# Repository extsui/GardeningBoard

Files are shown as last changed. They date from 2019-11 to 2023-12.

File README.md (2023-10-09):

# GardeningBoard
## 概要
- ガーデニングボードは着脱可能基板を自由に抜き差しして自分好みの作品を生み出せるというコンセプトの作品です。
- 当初はガーデニングにちなんで庭関連の基板ばかり作っていましたが、現在はガーデニングという手法をベースにした表現に概念を拡張しています。
  - 系譜：KawaiiMakeMyBoard --> GardeningBoard --> Fountain

## 基板
| 基板名 | 形状 | 概要 | 組み上げ対象作品 |
|---|---|---|---|
| Grass | 草 | 挿入部品 | GardeningBoard 等 |
| Tree | 木 | 挿入部品 | GardeningBoard 等 |
| House | 家 | 挿入部品 | GardeningBoard 等 |
| Land | 正方形 (旧式)・上部側 | 挿入部品用穴付き・半田接合式 | KawaiiMakeMyBoard 専用 |
| Base | 正方形 (旧式)・下部側 | カードエッジコネクタ土台 | KawaiiMakeMyBoard 専用 |
| Tile | 正六角形・上部側 | 挿入部品用穴付き | GardeningBoard 等 |
| Ground | 正六角形・下部側 | STM32F303 使用、Pillar からの信号を挿入分に分配<br>STM 未実装を Base の代わりとしても使用 | GardeningBoard 専用 |
| Pillar | 正六角形・最下部側 | SeeduinoXIAO 使用、単体動作可、GardeningBoard 制御の最上位 | GardeningBoard 専用 |
| Building | 縦長長方形・挿入部品  | 7セグ6桁x6行、GardeningBoard と互換性無し | 新規 |
| Fountain | 正六角形・下部側 | XIAO-ESP32C3 使用、Building・Tile 想定 | 新規 |

※順番は開発順

## プログラム
- Firmware/Balan
  - Ground に搭載されている STM32F303 向けのプログラム
  - 上位 I2C から受け取ったデータ (点灯パターン等) を元に、下位 I2C に接続されている HT16K33 を制御する
- M5Stack/Pump
  - PC から USB シリアル経由で受信したデータを Balan に送信する M5Stack 向けのプログラム
  - Balan への送信は I2C に変換して GROVE ケーブル経由で行う
  - GardeningBoard 開発時向けに使用したもので、GardeningBoard 最終系には含まれていない
- Tools/PruningTool
  - Pump と対応する PC 側の制御ツール (C# フォームアプリ)
  - 草/木/家/土等の基本パーツ一つ一つの点灯パターン作成・検討に使用
- Seeedino/Pillar
  - Pillar 基板に搭載されている SeeeduinoXIAO 向けのプログラム
  - PC から USB シリアル経由で受信したデータを Balan に送信する (Pump と立ち位置は似ている)
  - スタンドアローン動作も想定している
  - Pillar 基板に搭載されている以下を制御する
    - タクトスイッチ (状態遷移用)
    - DFPlayerMp3 基板 (音楽再生用)
    - microSD (点灯表示シナリオ読み込み用)
    - ボリューム2個 (輝度調整・表示周期変更用)
    - I2C マスタ GROVE コネクタ (Balan への信号用)
    - 0.96 inch I2C 有機 EL グラフィックス表示器 (各種情報表示用)
- Tools/Sprinkler
  - Pillar と対応する PC 側の制御ツール (C# WPF)
  - PruningTool のように基本パーツの点灯パターン検討も出来なくはないが、<br>Sprinkler はどちらかというと点灯パターンを組み合わせた GardeningBoard 全体の表示シナリオ検討・作成に使用することを想定
  - 表示シナリオ検討は以下の手順で行う
    - GardeningBoard (Pillar) と接続する
    - リアルタイム制御用のテキストボックスにフォーカスを当てた状態にする
    - キーボードのキーそれぞれに各パーツと表示パターンが割り当ててあるので自由にキー入力する
  - 作成した表示シナリオを Pillar で再生できる形式に変換・ファイル出力できる (ハズ)
- Tools/PatternConverter
  - 基本パーツの複雑な点灯パターン検討・作成用の Python スクリプト
  - 点灯パターンは yml ファイルで定義し、以下の二つに変換する
    - C/C++ 形式 (Balan のプログラムに埋め込む用)
    - C# 形式 (Sprinkler のシナリオ検討で点灯パターンを入力補完するためのパターン enum 定義用)
- Tools/BuildingPainter
  - TODO:

※順番は開発順

## 代表的な構成
### KawaiiMakeMyBoard 
| 基板名 | 個数 |
|---|---|
| Grass  | 2 |
| Tree | 1 |
| Land | 1 |
| Base | 1 |

### GardeningBoard
| 基板名 | 個数 | 備考 |
|---|---|---|
| Grass  | 3 | 手前側に3個 |
| Tree | 3 | 奥側に3個 |
| House  | 1 | 中央に1個 |
| Tile | 7 | - |
| Ground | 7 | STM 実装は2個、残りは中継用 |
| Pillar | 1 | 中央基板のさらに下に配置 |

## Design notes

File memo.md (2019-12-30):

# リリース履歴
- Grass v1.0
    - D12のシルクが逆向きになっている。
        ネットリスト再読み込みすれば逆向きであることがわかる。
    
- Grass v2.0
    - D12のシルク不具合修正。
    - カードエッジコネクタ5Pに修正。

# Tips
- KiCADのガバーデータの名前を変更しなくても発注できることを確認。(2019/05/26)

# 不具合/改善/対策メモ
- Grassで、カードエッジコネクタ部のベタが下にちょっと喰い込んでてイマイチ。
    下層のLEDのベタのY座標と合わせた方がいいかも。(2019/06/01)
- Baseで、GROVEコネクタは上方向にスペース的に刺せない。
    L字コネクタを刺そうとすると向き的に下方向にしか刺せない。
    -->コネクタ(配線)の向きを変える必要がある。

# 作品名案
- Gardening Board (外向け)
- KawaiiMakeMYBoard (内向け)
    ※でも流す曲はYPT？
- えくすとのアトリエ
- Extronics Gerden (Ext + -tronicsの造語)
- こころの庭
- Grass Growing

# アイデア
- 木の上に星つける
- 土台は黒色が落ち着くかも？
- 土台を六角形構造にする
    - パーツの底面が枠外に飛び出るのは見栄えが悪いので
      六角形にするなら10cm*10cmの枠を越えるのは必須。
    - --> 10cm*10cmにちょうど収まる形式とする方向で確定。

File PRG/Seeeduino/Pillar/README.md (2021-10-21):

# フォルダ構成
- Sd/
  - XIAO から読み込む SD カードのルートに格納するデータ。
    ※DFPlayerMini の SD に保存する BadApple の mp3 は
      リポジトリには含めないので別途用意すること。
- Make/
  - BadApple 用データ生成スクリプトおよび生成用フォルダ。

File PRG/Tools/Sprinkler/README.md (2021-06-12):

# Sprinkler

## 実行手順
以下のフォルダ構成で Sprinkler.exe を実行してください。
```
.
├── Sprinkler.exe
└── Music/
    ├── Wizards_in_Winter.mp3
    ├── ...(曲を増やす場合)
    └── ...(同上)
```

## 設計メモ
### MIDI ライブラリ
MIDI ライブラリの選定基準は以下の通り。
- MIDI 鍵盤からキー入力とベロシティを取得できること。
- 使い勝手がシンプルであること。

上記から midi-dot-net を選択した。

補足メモは以下の通り。
- NuGet でトップに出るのは managed-midi だが複雑そうだったので却下
- midi-dot-net にサンプルがついててわかりやすかった
- だが midi-dot-net が .NETCore 未対応でプロジェクトを
  .NETFramework に戻す羽目に…

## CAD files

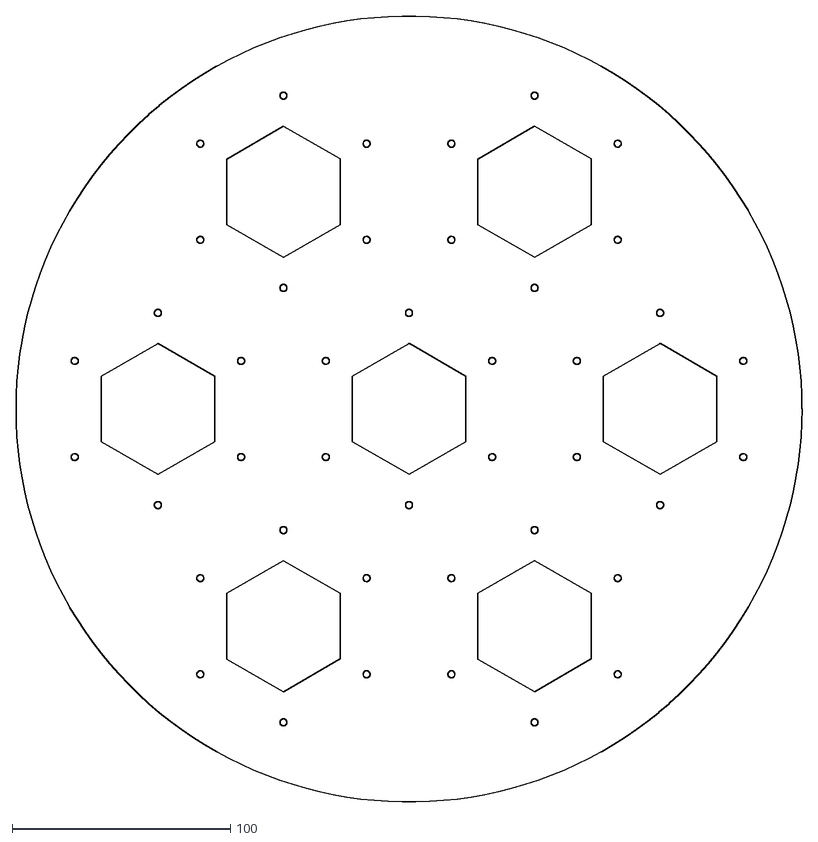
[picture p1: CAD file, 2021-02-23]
CAD/Floor.dxf
360.0 x 359.9

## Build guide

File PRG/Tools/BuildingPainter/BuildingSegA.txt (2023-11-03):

0x00, 0x21, 0x3B, 0x3B, 0x3B, 0x00, 
0x00, 0x00, 0x80, 0x80, 0x80, 0x00, 
0x00, 0x00, 0x00, 0x00, 0x00, 0x00, 
0x00, 0x00, 0x00, 0x00, 0x00, 0x00, 
0x00, 0x00, 0x00, 0x00, 0x00, 0x00, 
0x00, 0x00, 0x00, 0x00, 0x00, 0x00, 

00213B3B3B00000080808000000000000000000000000000000000000000000000000000

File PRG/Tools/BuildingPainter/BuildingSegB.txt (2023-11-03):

0x00, 0x00, 0x00, 0x00, 0x00, 0x00, 
0x00, 0x00, 0x00, 0x00, 0x71, 0x1E, 
0x00, 0x00, 0x00, 0x00, 0xE2, 0x8E, 
0x00, 0x00, 0x00, 0x00, 0x00, 0x00, 
0x00, 0x00, 0x00, 0x00, 0x00, 0x00, 
0x00, 0x00, 0x00, 0x00, 0x00, 0x00, 

00000000000000000000711E00000000E28E000000000000000000000000000000000000

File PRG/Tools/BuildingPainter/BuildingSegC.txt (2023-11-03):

0x00, 0x00, 0x00, 0x00, 0x00, 0x00, 
0x00, 0x00, 0x00, 0x00, 0x00, 0x00, 
0x00, 0x00, 0x00, 0x00, 0x00, 0x00, 
0x00, 0x00, 0x00, 0x00, 0x31, 0x1A, 
0x00, 0x00, 0x00, 0x00, 0xE3, 0x8E, 
0x00, 0x00, 0x00, 0x00, 0x00, 0x00, 

00000000000000000000000000000000000000000000311A00000000E38E000000000000

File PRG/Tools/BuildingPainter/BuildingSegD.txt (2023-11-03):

0x00, 0x00, 0x00, 0x00, 0x00, 0x00, 
0x00, 0x00, 0x00, 0x00, 0x00, 0x00, 
0x00, 0x00, 0x00, 0x00, 0x00, 0x00, 
0x00, 0x00, 0x00, 0x00, 0x00, 0x00, 
0x00, 0x01, 0x11, 0x11, 0x00, 0x00, 
0x00, 0xC0, 0xC6, 0xC6, 0x04, 0x00, 

00000000000000000000000000000000000000000000000000011111000000C0C6C60400

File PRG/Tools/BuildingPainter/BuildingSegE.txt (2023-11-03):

0x00, 0x00, 0x00, 0x00, 0x00, 0x00, 
0x00, 0x00, 0x00, 0x00, 0x00, 0x00, 
0x00, 0x00, 0x00, 0x00, 0x00, 0x00, 
0x21, 0x1A, 0x00, 0x00, 0x00, 0x00, 
0xF3, 0x8E, 0x00, 0x00, 0x00, 0x00, 
0x00, 0x00, 0x00, 0x00, 0x00, 0x00, 

000000000000000000000000000000000000211A00000000F38E00000000000000000000

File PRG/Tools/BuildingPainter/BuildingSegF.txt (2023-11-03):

0x00, 0x00, 0x00, 0x00, 0x00, 0x00, 
0x21, 0xFF, 0x00, 0x00, 0x00, 0x00, 
0x61, 0xCE, 0x00, 0x00, 0x00, 0x00, 
0x00, 0x00, 0x00, 0x00, 0x00, 0x00, 
0x00, 0x00, 0x00, 0x00, 0x00, 0x00, 
0x00, 0x00, 0x00, 0x00, 0x00, 0x00, 

00000000000021FF0000000061CE00000000000000000000000000000000000000000000

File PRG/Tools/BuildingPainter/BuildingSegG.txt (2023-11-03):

0x00, 0x00, 0x00, 0x00, 0x00, 0x00, 
0x00, 0x00, 0x00, 0x00, 0x00, 0x00, 
0x00, 0x01, 0x11, 0x11, 0x00, 0x00, 
0x00, 0x40, 0xC6, 0xC6, 0x84, 0x00, 
0x00, 0x00, 0x00, 0x00, 0x00, 0x00, 
0x00, 0x00, 0x00, 0x00, 0x00, 0x00, 

0000000000000000000000000001111100000040C6C68400000000000000000000000000

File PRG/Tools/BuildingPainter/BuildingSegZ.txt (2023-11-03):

0x00, 0x00, 0x00, 0x00, 0x00, 0x00, 
0x00, 0x00, 0x00, 0x00, 0x00, 0x00, 
0x00, 0x00, 0x00, 0x00, 0x00, 0x00, 
0x00, 0x00, 0x00, 0x00, 0x00, 0x00, 
0x00, 0x00, 0x00, 0x00, 0x00, 0x00, 
0x00, 0x00, 0x00, 0x00, 0x00, 0xC6, 

0000000000000000000000000000000000000000000000000000000000000000000000C6

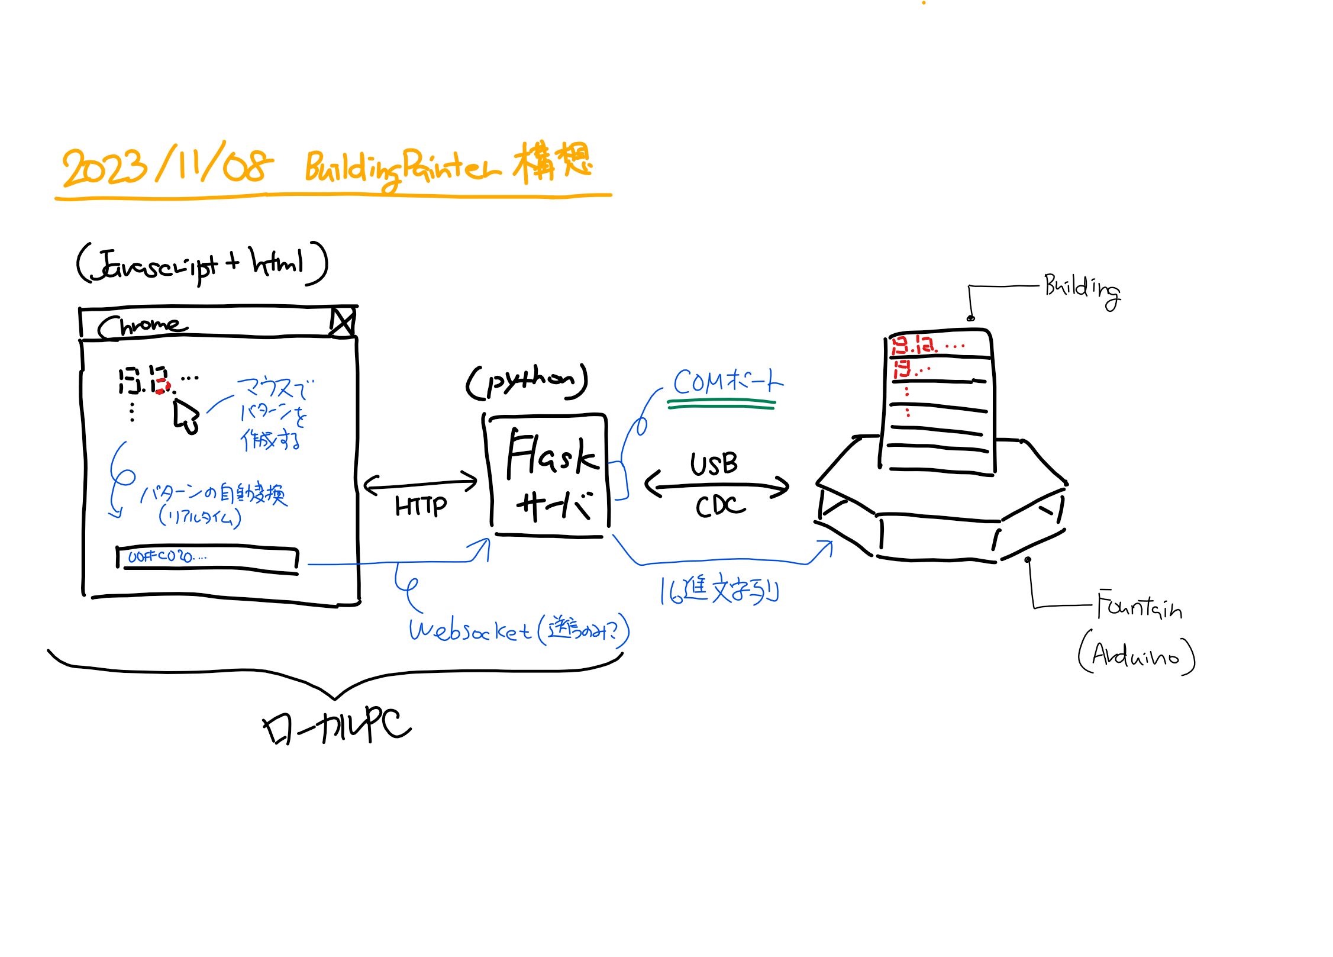
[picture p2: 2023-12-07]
PRG/Tools/BuildingPainter/20231108_BuildingPainter構想.png

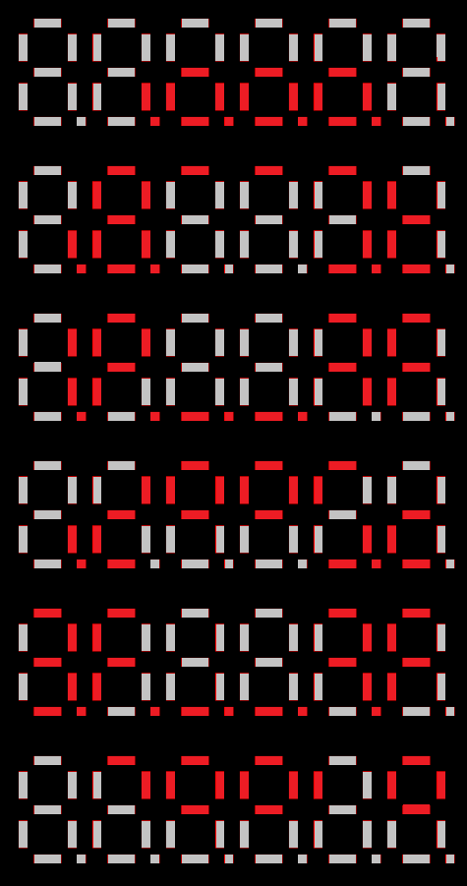
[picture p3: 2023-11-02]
PRG/Tools/BuildingPainter/4_正論理.png

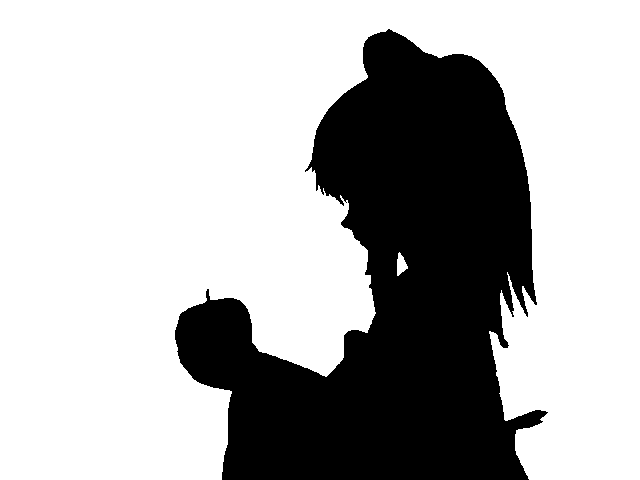
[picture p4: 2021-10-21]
PRG/Seeeduino/BadApple/Make/Input/g0082.bmp

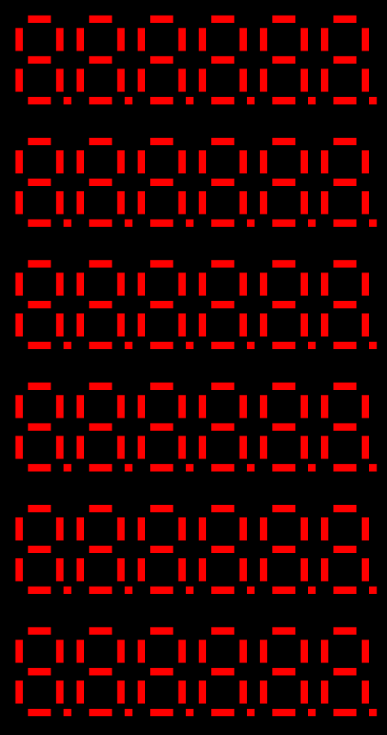
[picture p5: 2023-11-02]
PRG/Tools/BuildingPainter/1_全点灯.png

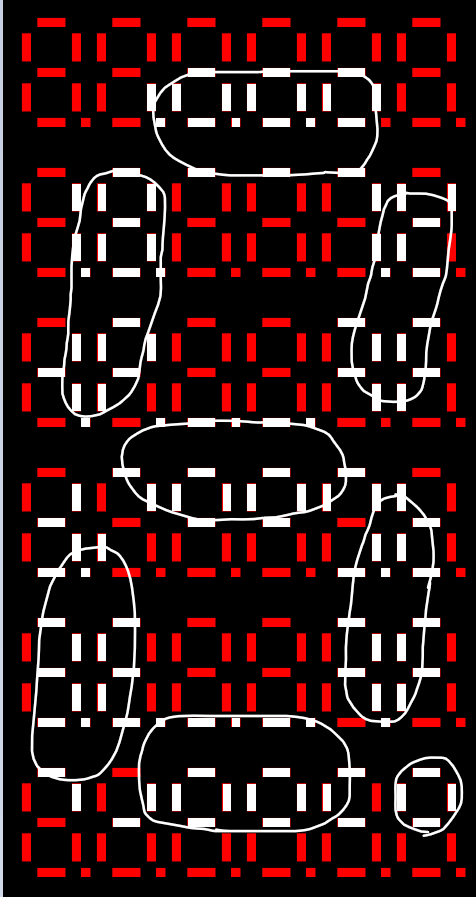
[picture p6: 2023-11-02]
PRG/Tools/BuildingPainter/2_仮配置_ガワ.png

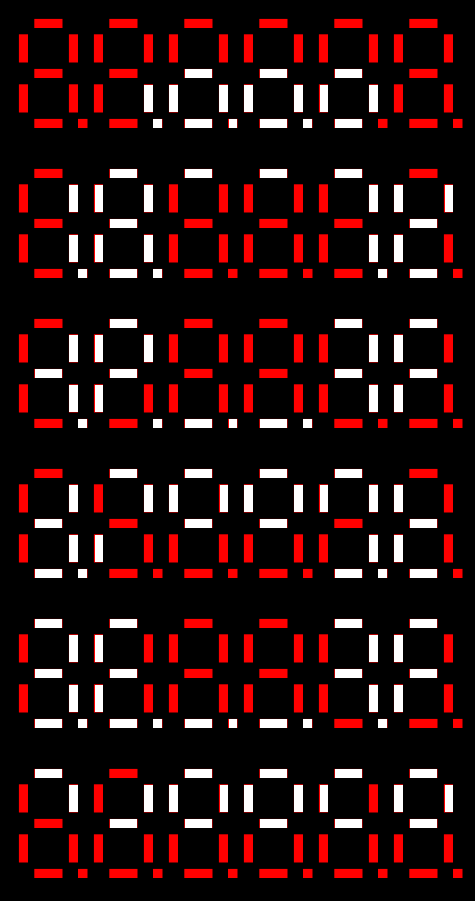
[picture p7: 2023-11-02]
PRG/Tools/BuildingPainter/2_仮配置.png

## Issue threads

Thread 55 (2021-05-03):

Sprinkler は絶対時間指定でパターンを実行できる

extsui, 2021-05-03:
- パターン実行開始時を0とした絶対時間指定
- 追加要素：
  - テンポ＋小節番号で指定できるとなおよい
  - 依存パターン実行ができると楽かもしれない (直前のパターンが終わったら自動的に実行される)

extsui, 2021-05-08:
曲の演出を考え始めると曲の途中からのパターン確認が必ずやりたくなるはず。
CommandSequencer 対応はすぐできるが、音声ファイル再生も途中再生/中断などに対応する必要がある。
調べてみると、NAudio とかいうのがつかいやすそう。
- Seek 対応している
- .mp3 ファイルにも対応している

extsui, 2021-05-15:
アニメーションのポイント
- 演出は曲の雰囲気の切り替えポイント以外では大きく切り替えない (逆に言えばAメロ/Bメロ/サビのような区切りで大きく切り替える)
-- 次の動きがある程度予測できる方が脳の負担が少ない (曲自体がそういう構造。8小節くらいが塊になってる)
-- 木の光を小節ごとに一本ずつ増やしていくとかはあり。

extsui, 2021-06-12:
> 依存パターン実行ができると楽かもしれない (直前のパターンが終わったら自動的に実行される)
上記はあると便利かもしれないが必須ではないのでとりあえずスルー。

GUI にシークバーをつけるのもありだったが、演出を考える上では開始時刻を設定できれば十分なので、とりあえずスルー。

Closed 2021-06-12.

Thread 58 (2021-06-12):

Sprinkler で Wizards_in_Winter の演出を最後まで作成する

extsui, 2021-06-12:

extsui, 2021-06-12:
Issue #55, Pull Request #57 で一部試作済み。

以下は #55 からのメモ。
```
アニメーションのポイント

演出は曲の雰囲気の切り替えポイント以外では大きく切り替えない (逆に言えばAメロ/Bメロ/サビのような区切りで大きく切り替える)
-- 次の動きがある程度予測できる方が脳の負担が少ない (曲自体がそういう構造。8小節くらいが塊になってる)
-- 木の光を小節ごとに一本ずつ増やしていくとかはあり。
```

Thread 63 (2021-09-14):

Pillar の評価用に BadApple 再生機能を作る

extsui, 2021-09-14:
- Seeeduino XIAO Expansion ボードを使用
- BadApple データは SD に保存
  - 性能面から、約 2000 枚の二値画像から画像データのみを 1 ファイルに結合
- 動画像は 0.96 inch OLED に出力・表示
- 音声は DFPlayerMini に UART 経由で指示
- ボリュームで DFPlayerMini の音量を調整

Closed 2021-10-21.

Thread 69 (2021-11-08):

Seeeduino XIAO 環境に Pump ライブラリを適合させる

extsui, 2021-11-08:
#68 で Pump の雑移植はできたが以下の問題が残っているのでそれを解決する
* 疑似マルチタスク動作になっていない
** 音量や輝度を動的に変更できない
** ボタンイベントが取れない
* RAM 容量削減によりスクリプトの一括解析ができなくなる
** スクリプトファイルの逐次読み込み・逐次実行が必要

extsui, 2021-11-08:
電源投入後の初期状態をスクリプトステートにしておいた方が今後楽かもしれない。

以下の順で状態遷移を繰り返す。
1. スクリプト状態
2. BadApple 状態
3. Idle 状態

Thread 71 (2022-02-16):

コマンドシーケンスを実際に実行しなくてもスクリプト列を出力できるようにする

extsui, 2022-02-16:
現状はスクリプト列を吐き出すためにはコマンドシーケンスを実際に実行する必要がある。
理由は、Action クラスの塊になっていて Thread.Sleep() などを多用しているため。

現状の PROS/CONS：
- (+) GUI 上から雑に実行を試せる (が、非Actionにしたところでこのメリットは維持できるはず)
- (-) 実行するまでスクリプト列が確定しない
- (-) 毎回スクリプト列が異なる (ハズ)

extsui, 2022-02-20:
メモ：
- 文字列化する時に依存を減らしたい。
  - テンプレートコマンドクラスを作りたい。
  - ＝依存注入として m_garden /* 基板配置情報 */ を使い、各種コマンド文字列を生成できるクラス。
  - ＝音楽再生と組み合わせるときの時間情報とどう組み合わせるかが大事かも。
  - 文字列ファイルにしたときに何のコマンド内容かという情報をコメントとして吐き出したい。

extsui, 2023-04-27:
登録コマンドとか輝度アップコマンド、展示モードコマンドとかはすぐダンプできるっしょ。

あとはファイル名をちゃんと決めた上で一括出力が欲しい。アドレスかえたあとに際生成する手間があるので。

extsui, 2023-04-27:
Pillar側はスクリプトファイルを一行先読みしとけばよさげ。
というか「現在時刻より先だったらそれまで待つ」&「末尾まで読み続ける」でいい気がする。

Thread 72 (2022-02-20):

輝度設定をフレーズ単位で設定できるようにする

extsui, 2022-02-20:
そのためには以下が必要。
- TurnOnSmoothly 系とかに輝度設定の反映が必要。
- 輝度ツマミの仕様追加が必要かも。
  - 例：ツマミが中央なら輝度設定値*1.0、ツマミが左端なら *0.1 (最小輝度に丸める)、ツマミが右端なら *10.0 (最大輝度に丸める) とか。
- 実機側が無くても判定できるようにアプリにスライドバー追加が必要かも？

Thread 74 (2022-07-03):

Pillar+Ground の機能を集約した直線系の基板を作る

extsui, 2022-07-03:
* マイコンは Seeeduino XIAO BLE を採用する。
* I2C ロジックはちゃんと 5V にする。
* 5PIN ボックスコネクタを縦に数個配置する。
* 横方向への拡張を検討しておく。(ピンヘッダと GROVE)

extsui, 2022-07-10:
基板の形状は魚っぽくするのはどうか？
fish？

魚が船を支えているイメージ

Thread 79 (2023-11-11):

BuildingPainter でブラウザ経由でリアルタイムで実機の描画編集ができるようにする

extsui, 2023-11-11:
「BuildingPainter (JS) --> Flask (python) --> 実機」の経路を開通させる必要がある。
* Server 側コードの作成
* WebSocket 通信の開通
* Server で COM ポートを開くようにする
* 実機側で USB 受信した16進データのパーサーを書く

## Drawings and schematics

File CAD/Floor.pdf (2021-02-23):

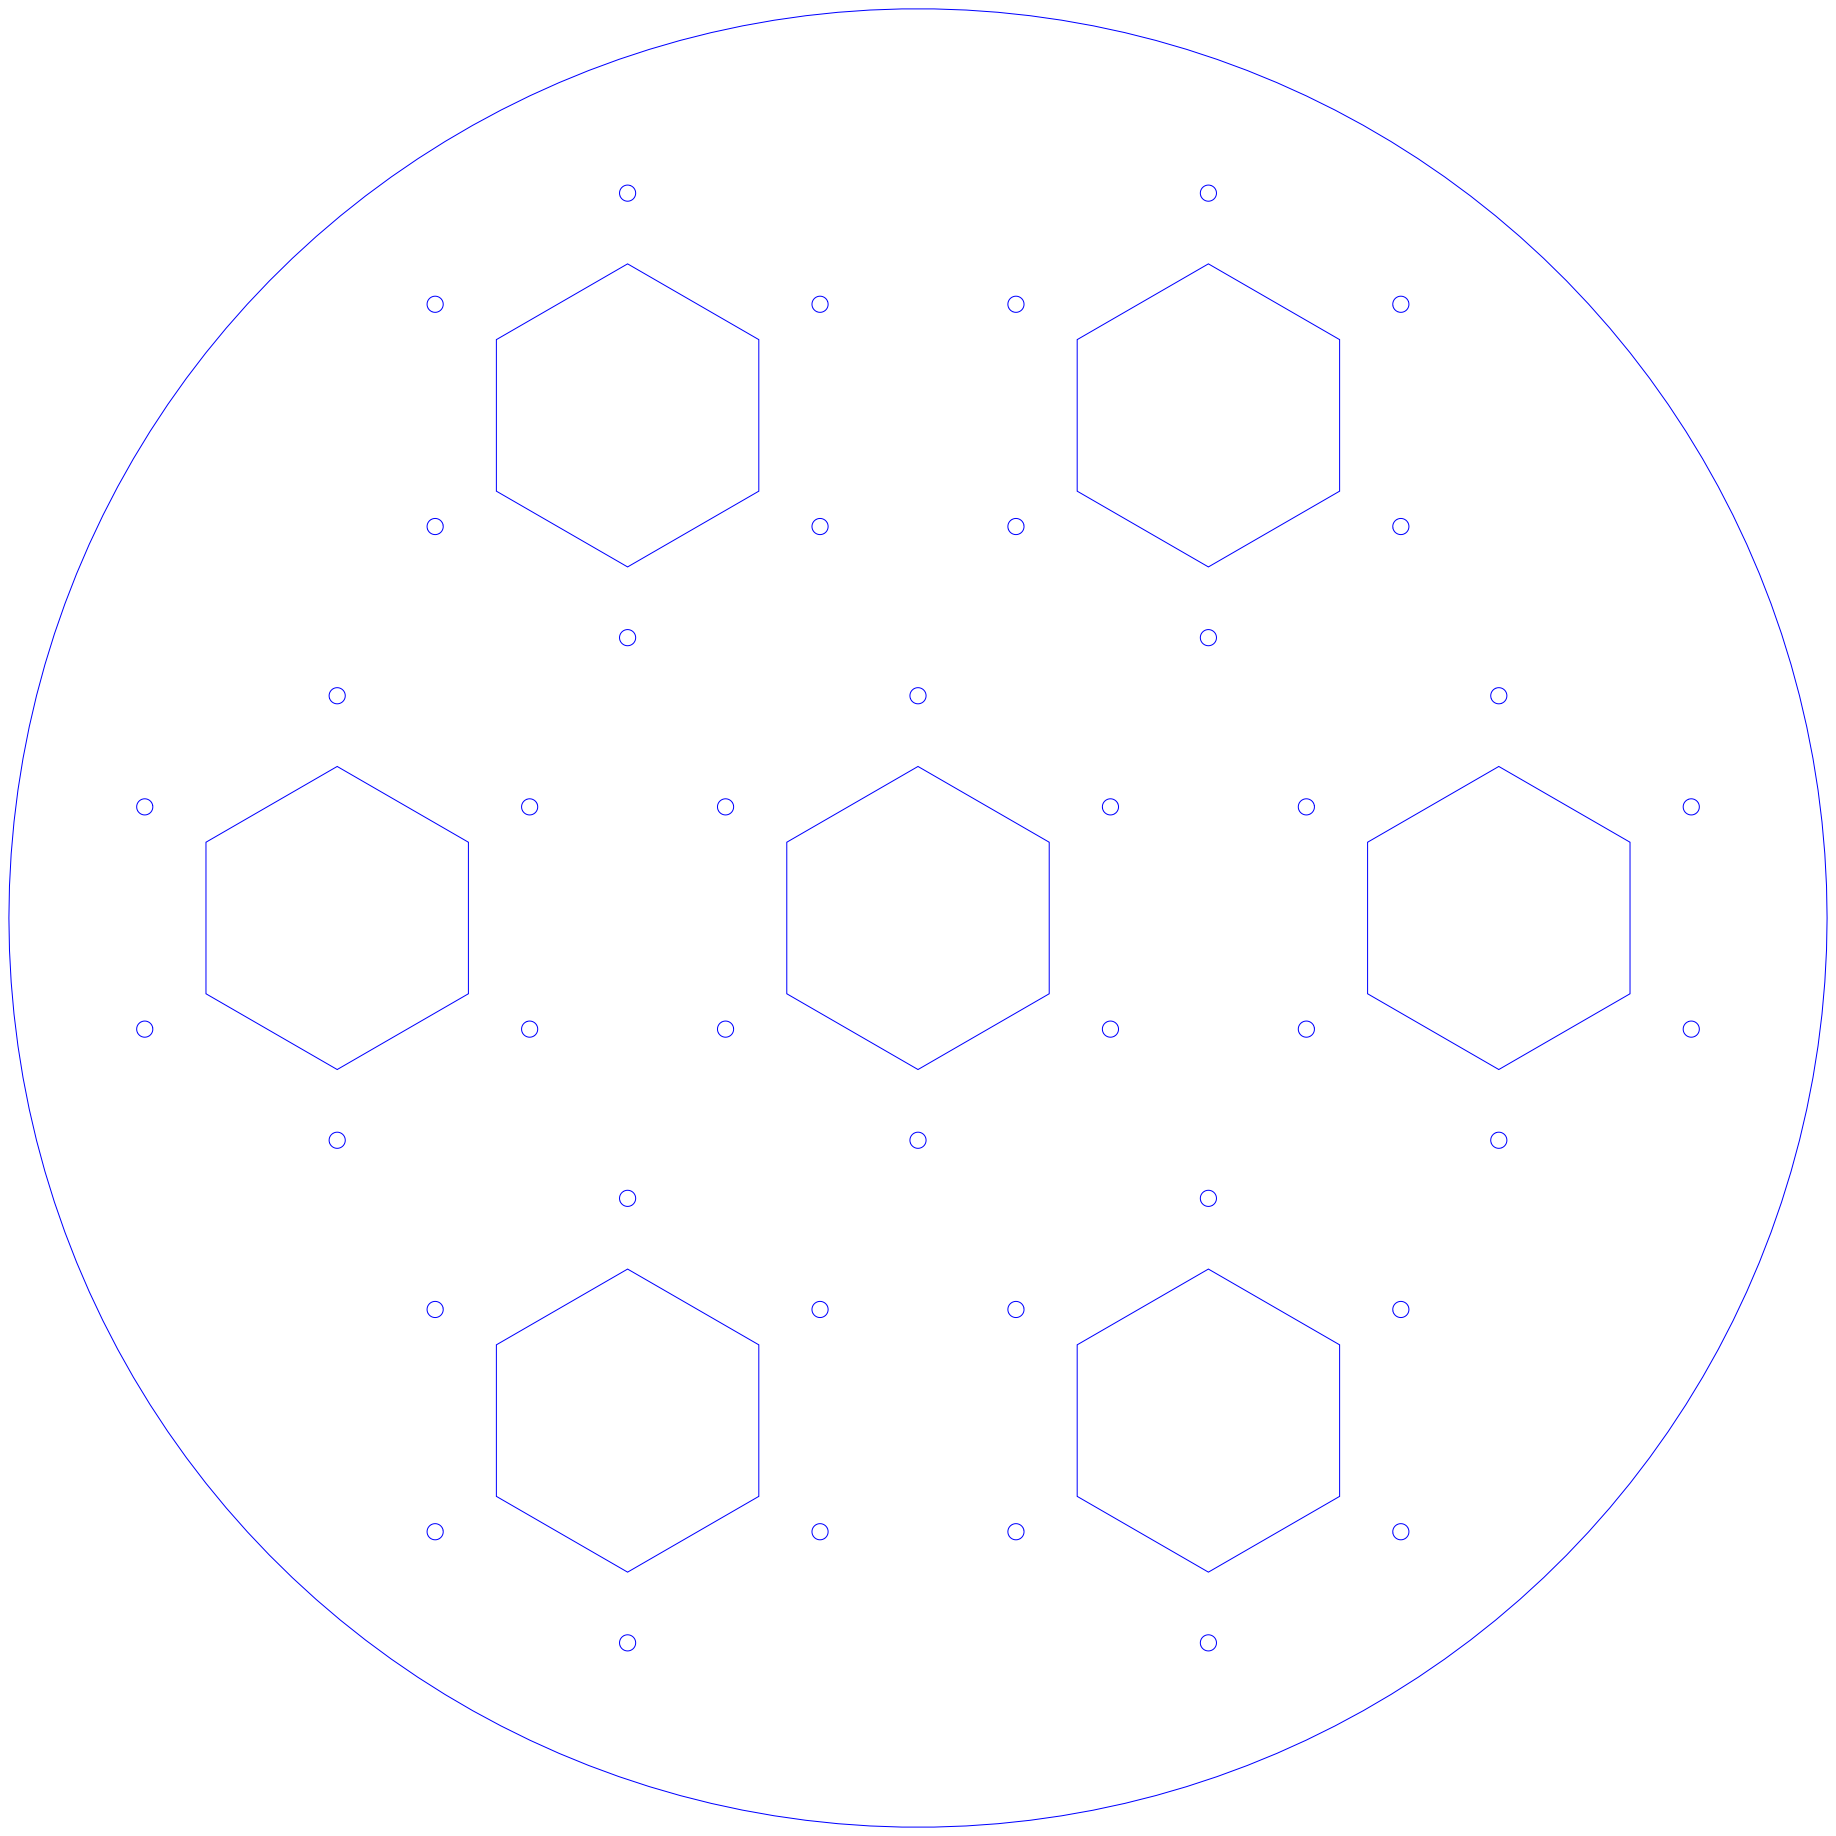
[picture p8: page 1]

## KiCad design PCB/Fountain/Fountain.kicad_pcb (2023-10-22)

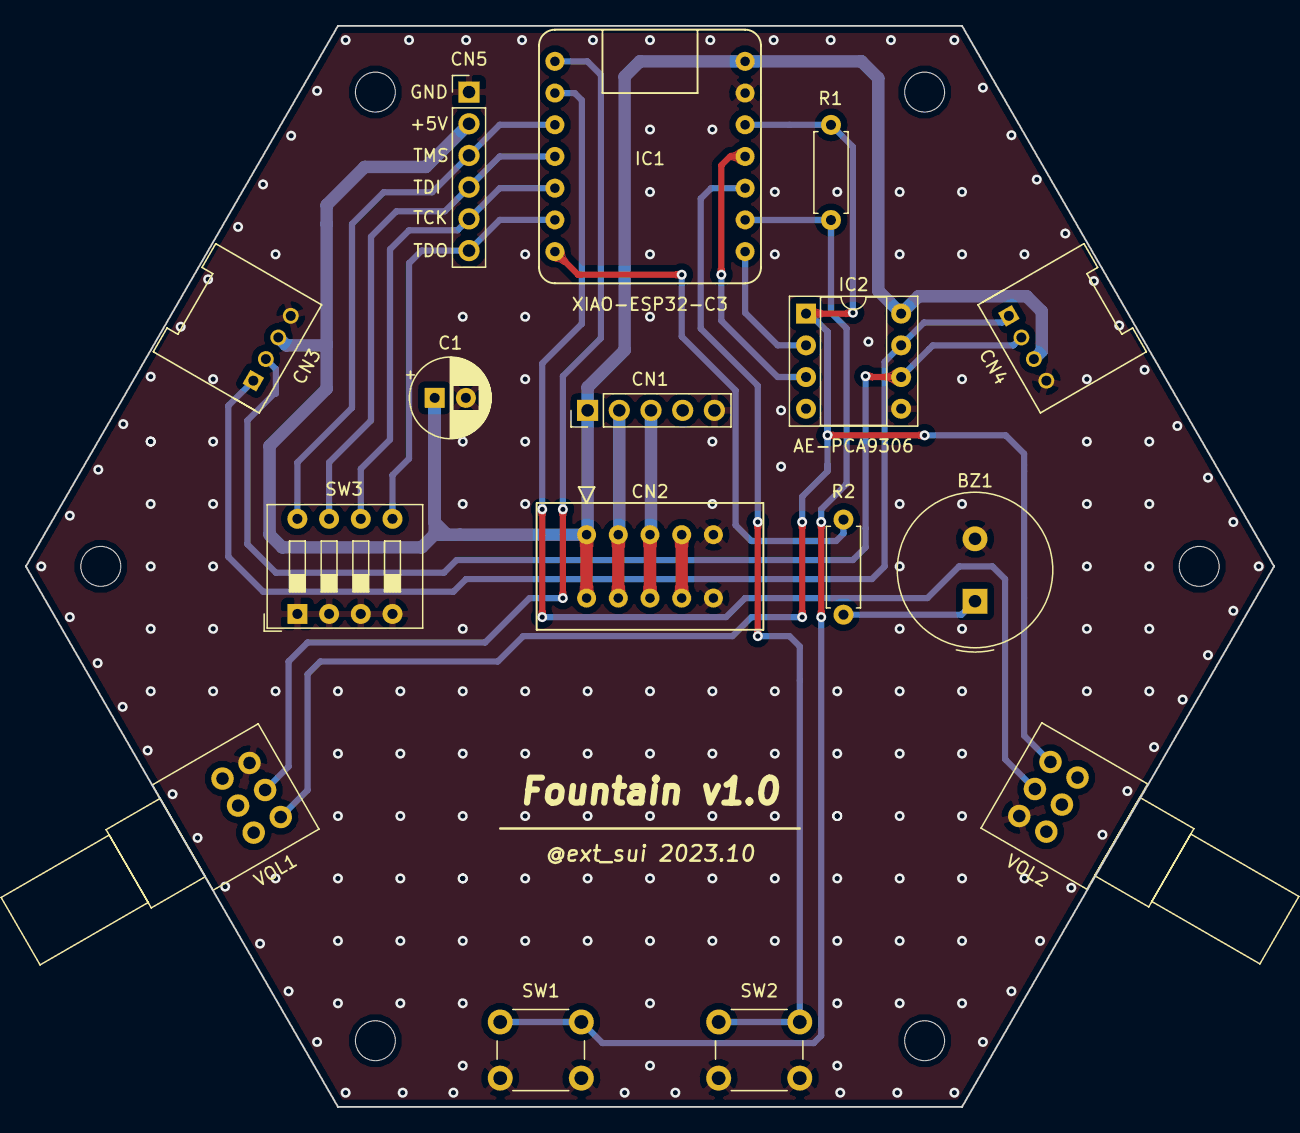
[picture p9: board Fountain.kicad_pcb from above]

Board: 2 copper layers, 100.0 x 86.6 mm, 22 parts (0 on the bottom side), 17 nets.

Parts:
BZ1: Buzzer; Buzzer_TDK_PS1240P02BT_D12.2mm_H6.5mm
C1: CP; CP_Radial_D6.3mm_P2.50mm
CN1: Conn_01x05_Female; PinHeader_1x05_P2.54mm_Vertical
CN2: CardEdgeConnector5P; CONN_CARD_EDGE_395-010-521-201
CN3, CN4: GROVE_IIC_5V; HW4-2.0-90D
CN5: JTAG; PinHeader_1x06_P2.54mm_Vertical
H1, H2, H3, H4, H5, H6: MountingHole; MountingHole_3.2mm_M3
IC1: XIAO-ESP32-C3; SeeeduinoXIAO
IC2: AE-PCA9306; DIP-8_W7.62mm_Socket
R1: 10k; R_Axial_DIN0207_L6.3mm_D2.5mm_P7.62mm_Horizontal
R2: 1k; R_Axial_DIN0207_L6.3mm_D2.5mm_P7.62mm_Horizontal
SW1, SW2: (TBD); SW_PUSH_6mm_H8.5mm
SW3: DIPSW-4P; SW_DIP_SPSTx04_Slide_9.78x12.34mm_W7.62mm_P2.54mm
VOL1, VOL2: (TBD); Potentiometer_Alps_RK097_Dual_Horizontal

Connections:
3V3: IC1.12, IC2.1, R1.2, VOL1.6, VOL2.6
5V: C1.1, CN1.1, CN2.1, CN3.3, CN4.3, CN5.2, IC1.14, IC2.8
GND: BZ1.2, C1.2, CN1.5, CN2.5, CN3.4, CN4.4, CN5.1, IC1.13, IC2.5, SW1.2, SW2.2, SW3.1, SW3.2, SW3.3, SW3.4, VOL1.4, VOL2.4
unnamed: BZ1.1, R2.2
unnamed: CN5.3, IC1.3, SW3.8
unnamed: CN5.4, IC1.4, SW3.7
unnamed: CN5.5, IC1.5, SW3.6
unnamed: CN5.6, IC1.6, SW3.5
unnamed: IC1.7, R2.1
unnamed: IC1.9, R1.1, SW1.1
unnamed: IC1.10, SW2.1
RV1: IC1.1, VOL1.5
RV2: IC1.2, VOL2.5
SCL_3V3: IC1.8, IC2.2
SCL_5V: CN1.3, CN2.3, CN3.1, CN4.1, IC2.7
SDA_3V3: IC1.11, IC2.3
SDA_5V: CN1.2, CN2.2, CN3.2, CN4.2, IC2.6

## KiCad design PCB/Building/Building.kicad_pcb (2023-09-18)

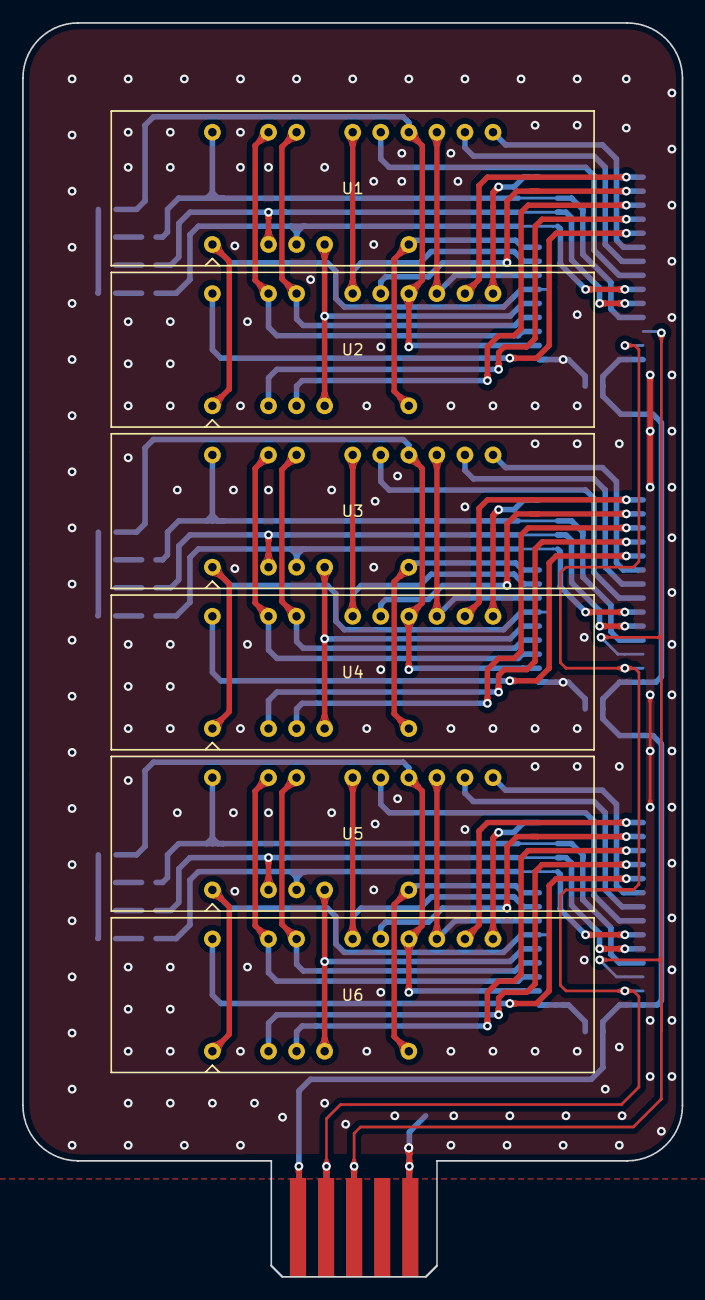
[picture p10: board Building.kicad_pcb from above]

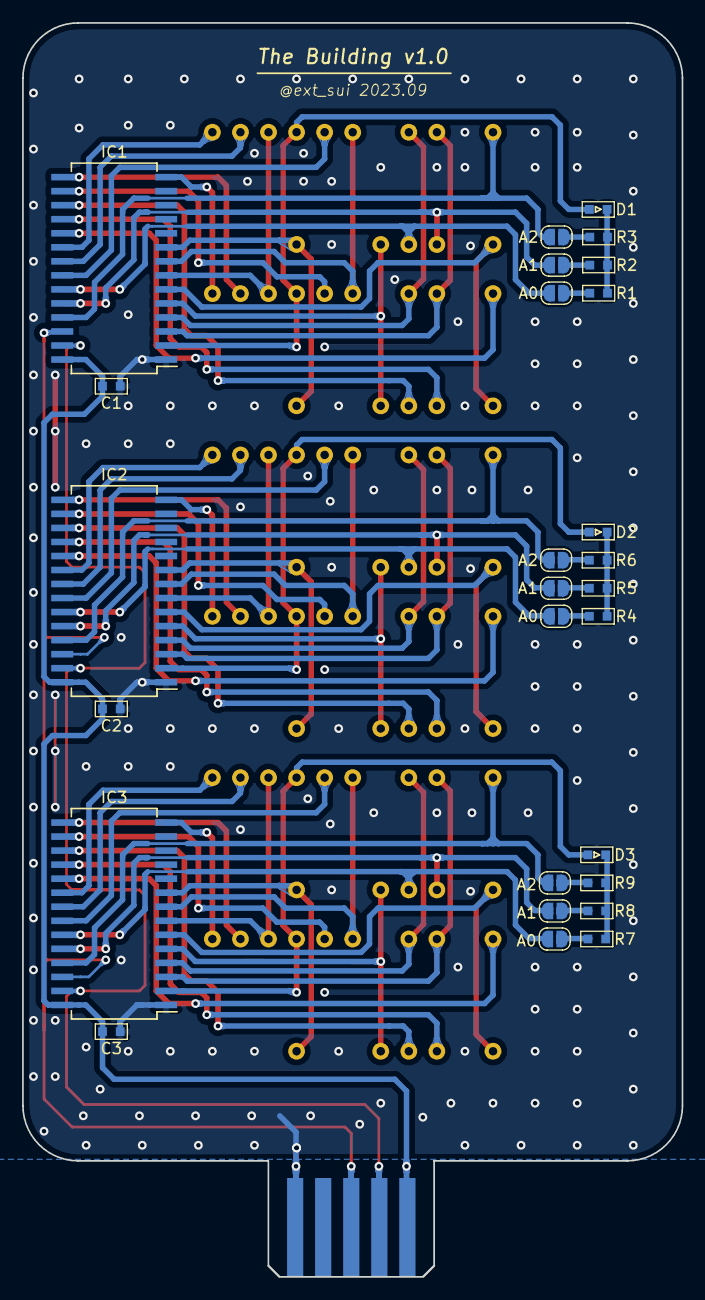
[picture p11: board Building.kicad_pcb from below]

Board: 2 copper layers, 59.7 x 113.5 mm, 34 parts (27 on the bottom side), 76 nets.

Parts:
C1, C2, C3: 0.1u; C_1608_HandSolderingCustom
D1, D2, D3: D; LED_1608_HandSolderingCustom
IC1, IC2, IC3: HT16K33-28SOP; SOIC-28W_7.5x18.7mm_P1.27mm
J1: Conn_01x05; EDAC_5P_P2.54mm
JP1, JP4, JP7: A0; SolderJumper-2_P1.3mm_Open_RoundedPad1.0x1.5mm
JP2, JP5, JP8: A1; SolderJumper-2_P1.3mm_Open_RoundedPad1.0x1.5mm
JP3, JP6, JP9: A2; SolderJumper-2_P1.3mm_Open_RoundedPad1.0x1.5mm
R1, R2, R3, R4, R5, R6, R7, R8, R9: 39k; R_1608_HandSolderingCustom
U1, U2, U3, U4, U5, U6: OSL60362_IX; OSL60362_XX

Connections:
+5V: C1.1, C2.1, C3.1, IC1.28, IC2.28, IC3.28, J1.1
/A_1: D1.2, IC1.2, U1.15, U2.15
/A_2: D2.2, IC2.2, U3.15, U4.15
/A_3: D3.2, IC3.2, U5.15, U6.15
/B_1: IC1.3, U1.20, U2.20
/B_2: IC2.3, U3.20, U4.20
/B_3: IC3.3, U5.20, U6.20
/CA1: IC1.25, JP3.2, U1.22
/CA2: IC1.24, JP2.2, U1.3
/CA3: IC1.23, JP1.2, U1.4
/CA4: IC1.22, U1.16
/CA5: IC1.21, U1.13
/CA6: IC1.20, U1.12
/CA7: IC1.19, U2.22
/CA8: IC1.18, U2.3
/CA9: IC1.17, U2.4
/CA10: IC1.16, U2.16
/CA11: IC1.15, U2.13
/CA12: IC1.14, U2.12
/CA13: IC2.25, JP6.2, U3.22
/CA14: IC2.24, JP5.2, U3.3
/CA15: IC2.23, JP4.2, U3.4
/CA16: IC2.22, U3.16
/CA17: IC2.21, U3.13
/CA18: IC2.20, U3.12
/CA19: IC2.19, U4.22
/CA20: IC2.18, U4.3
/CA21: IC2.17, U4.4
/CA22: IC2.16, U4.16
/CA23: IC2.15, U4.13
/CA24: IC2.14, U4.12
/CA25: IC3.25, JP9.2, U5.22
/CA26: IC3.24, JP8.2, U5.3
/CA27: IC3.23, JP7.2, U5.4
/CA28: IC3.22, U5.16
/CA29: IC3.21, U5.13
/CA30: IC3.20, U5.12
/CA31: IC3.19, U6.22
/CA32: IC3.18, U6.3
/CA33: IC3.17, U6.4
/CA34: IC3.16, U6.16
/CA35: IC3.15, U6.13
/CA36: IC3.14, U6.12
/C_1: IC1.4, U1.19, U2.19
/C_2: IC2.4, U3.19, U4.19
/C_3: IC3.4, U5.19, U6.19
/DP_1: IC1.9, U1.8, U2.8
/DP_2: IC2.9, U3.8, U4.8
/DP_3: IC3.9, U5.8, U6.8
/D_1: IC1.5, U1.5, U2.5
/D_2: IC2.5, U3.5, U4.5
/D_3: IC3.5, U5.5, U6.5
/E_1: IC1.6, U1.1, U2.1
/E_2: IC2.6, U3.1, U4.1
/E_3: IC3.6, U5.1, U6.1
/F_1: IC1.7, U1.14, U2.14
/F_2: IC2.7, U3.14, U4.14
/F_3: IC3.7, U5.14, U6.14
/G_1: IC1.8, U1.17, U2.17
/G_2: IC2.8, U3.17, U4.17
/G_3: IC3.8, U5.17, U6.17
GND: C1.2, C2.2, C3.2, IC1.1, IC2.1, IC3.1, J1.5
unnamed: D1.1, R1.2, R2.2, R3.2
unnamed: D2.1, R4.2, R5.2, R6.2
unnamed: D3.1, R7.2, R8.2, R9.2
unnamed: JP1.1, R1.1
unnamed: JP2.1, R2.1
unnamed: JP3.1, R3.1
unnamed: JP4.1, R4.1
unnamed: JP5.1, R5.1
unnamed: JP6.1, R6.1
unnamed: JP7.1, R7.1
unnamed: JP8.1, R8.1
unnamed: JP9.1, R9.1
SCL: IC1.26, IC2.26, IC3.26, J1.3
SDA: IC1.27, IC2.27, IC3.27, J1.2

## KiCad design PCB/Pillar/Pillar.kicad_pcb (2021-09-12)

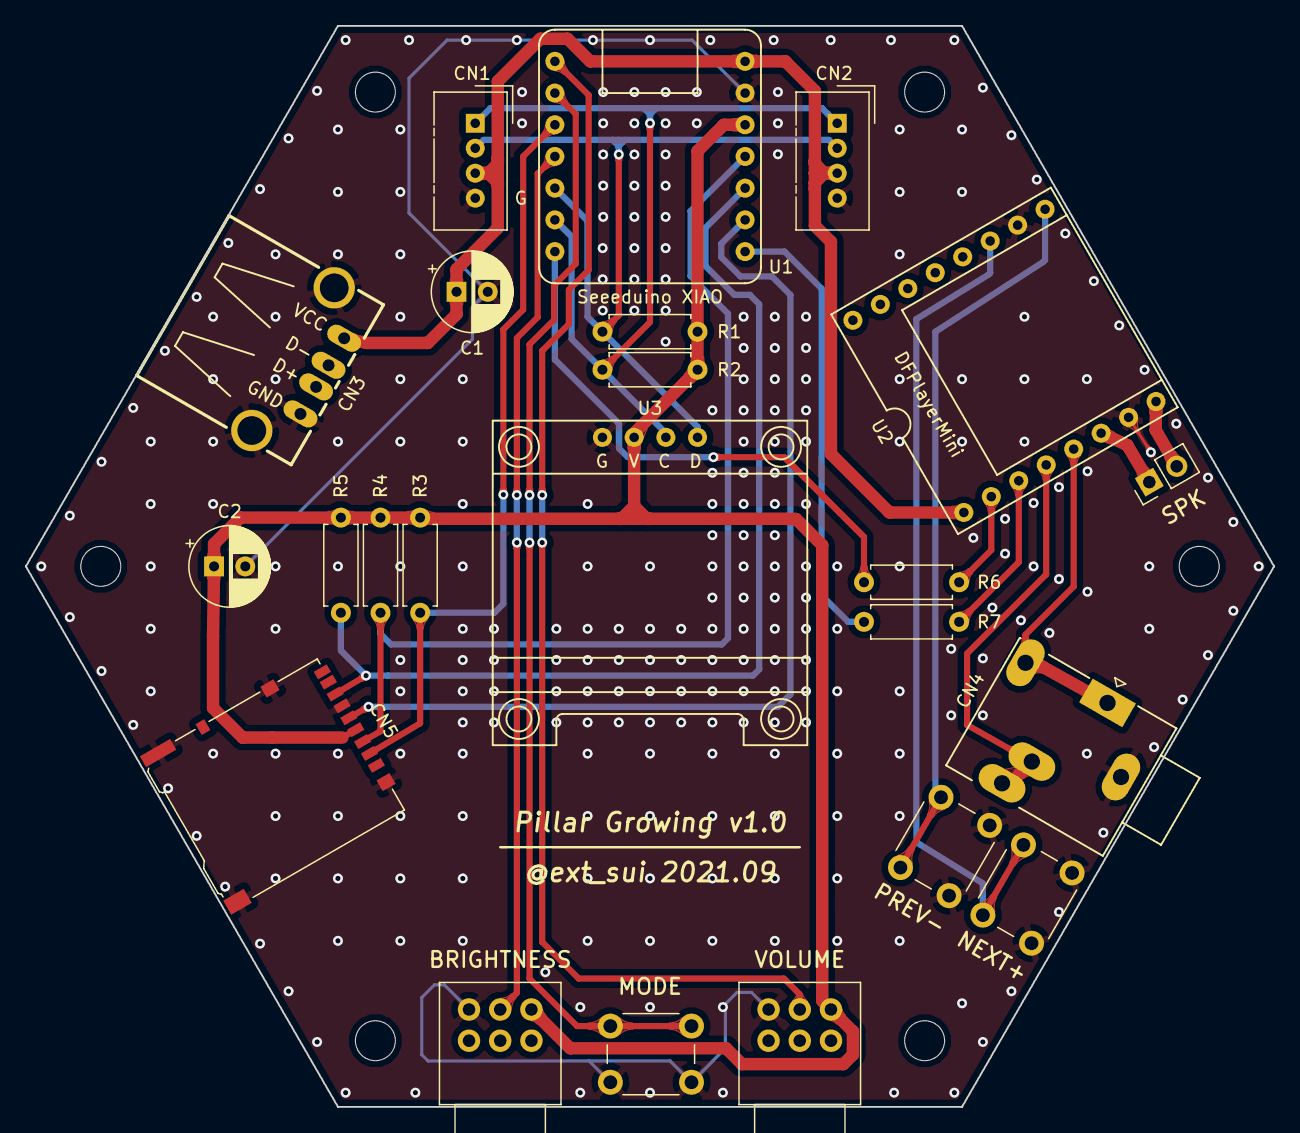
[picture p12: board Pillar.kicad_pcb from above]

Board: 2 copper layers, 100.0 x 86.6 mm, 29 parts (0 on the bottom side), 22 nets.

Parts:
C1, C2: 100u; CP_Radial_D6.3mm_P2.50mm
CN1, CN2: GROVE_IIC_5V; NS-Tech_Grove_1x04_P2mm_Vertical
CN3: USB_A; USB4+2P-2.0-90D
CN4: AudioJack3_SwitchTR; Jack_3.5mm_Ledino_KB3SPRS_Horizontal
CN5: Micro_SD_Card_Det_Hirose_DM3AT; microSD_HC_Hirose_DM3AT-SF-PEJM5
H1, H2, H3, H4, H5, H6: MountingHole; MountingHole_3.2mm_M3
J1: Speaker; PinHeader_1x02_P2.54mm_Vertical
R1, R2, R3, R4, R5: 4.7k; R_Axial_DIN0207_L6.3mm_D2.5mm_P7.62mm_Horizontal
R6, R7: 1k; R_Axial_DIN0207_L6.3mm_D2.5mm_P7.62mm_Horizontal
RV1: BRIGHTNESS; Potentiometer_Alps_RK097_Dual_Horizontal
RV2: VOLUME; Potentiometer_Alps_RK097_Dual_Horizontal
SW1: MDOE; SW_PUSH_6mm_H8.5mm
SW2: NEXT/VOL+; SW_PUSH_6mm_H8.5mm
SW3: PREV/VOL-; SW_PUSH_6mm_H8.5mm
U1: SeeeduinoXIAO
U2: DFPlayerMini
U3: OLED_128x64_IIC; OLED_128x64_0.96inch

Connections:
3V3: C2.1, CN5.4, R1.1, R2.1, R3.1, R4.1, R5.1, RV1.6, RV2.6, U1.12, U3.2
5V: C1.1, CN1.3, CN2.3, CN3.1, U1.14, U2.1
CS: CN5.2, R3.2, U1.3
GND: C1.2, C2.2, CN1.4, CN2.4, CN3.4, CN3.5, CN4.S, CN5.6, CN5.11, RV1.4, RV2.4, SW1.2, SW2.2, SW3.2, U1.13, U2.7, U2.10, U3.1
MISO: CN5.7, R5.2, U1.10
MOSI: CN5.3, R4.2, U1.11
unnamed: CN4.R, CN4.RN, U2.4
unnamed: CN4.T, CN4.TN, U2.5
unnamed: J1.1, U2.6
unnamed: J1.2, U2.8
unnamed: R6.1, U2.2
unnamed: R7.1, U2.3
unnamed: SW1.1, U1.2
unnamed: SW2.1, U2.11
unnamed: SW3.1, U2.9
RV_B: RV1.5, U1.4
RV_V: RV2.5, U1.1
RXD: R7.2, U1.8
SCK: CN5.5, U1.9
SCL: CN1.1, CN2.1, R2.2, U1.6, U3.3
SDA: CN1.2, CN2.2, R1.2, U1.5, U3.4
TXD: R6.2, U1.7

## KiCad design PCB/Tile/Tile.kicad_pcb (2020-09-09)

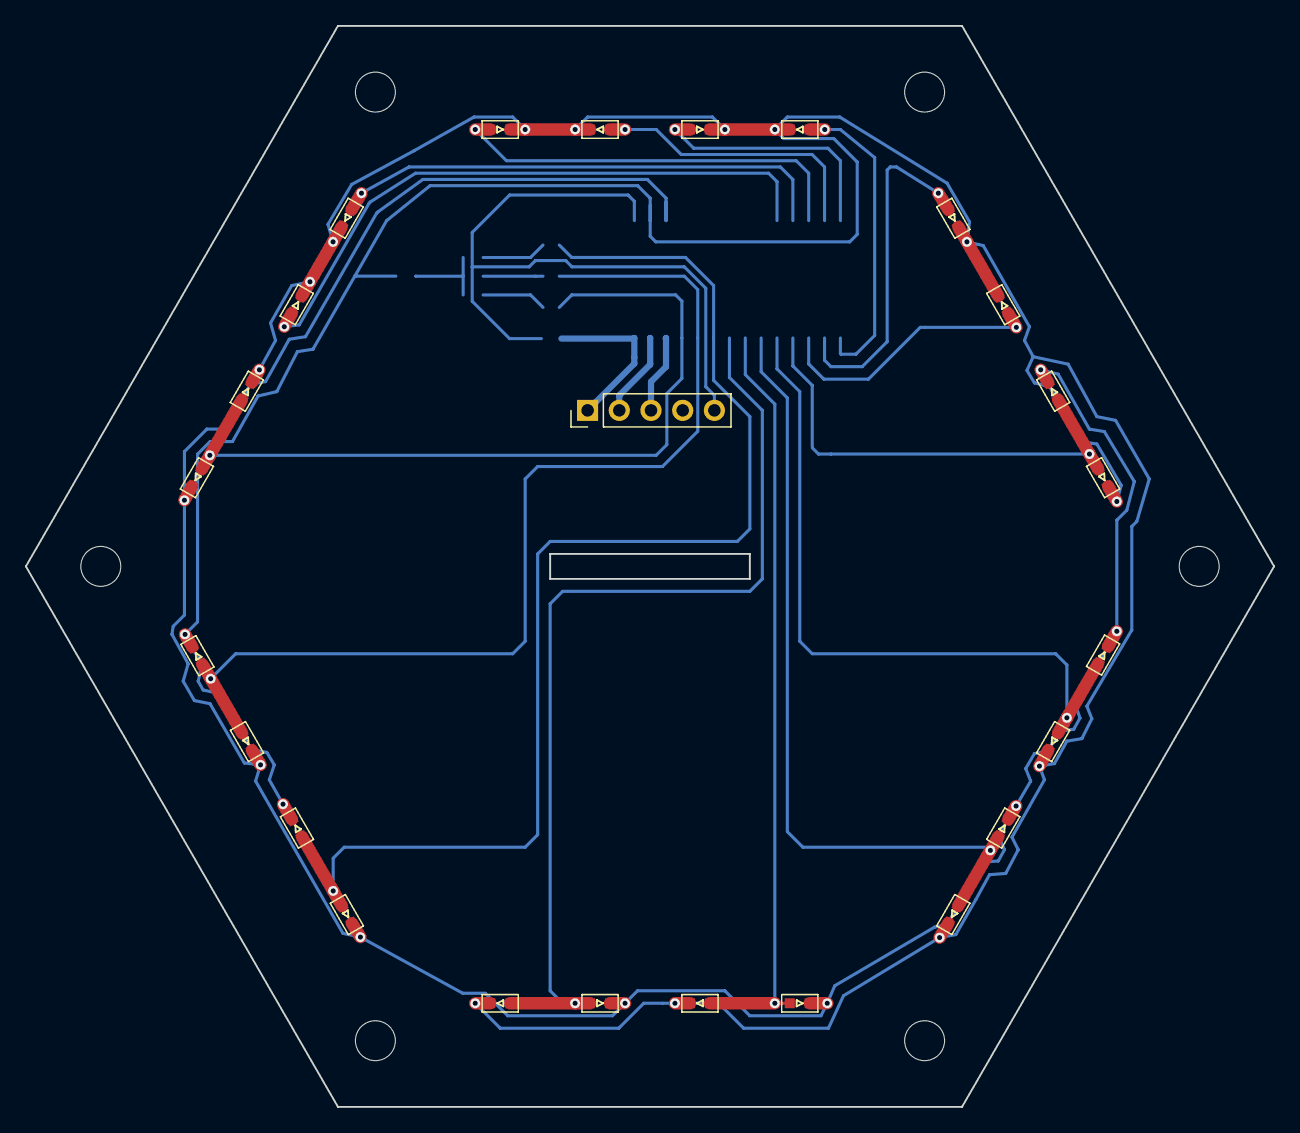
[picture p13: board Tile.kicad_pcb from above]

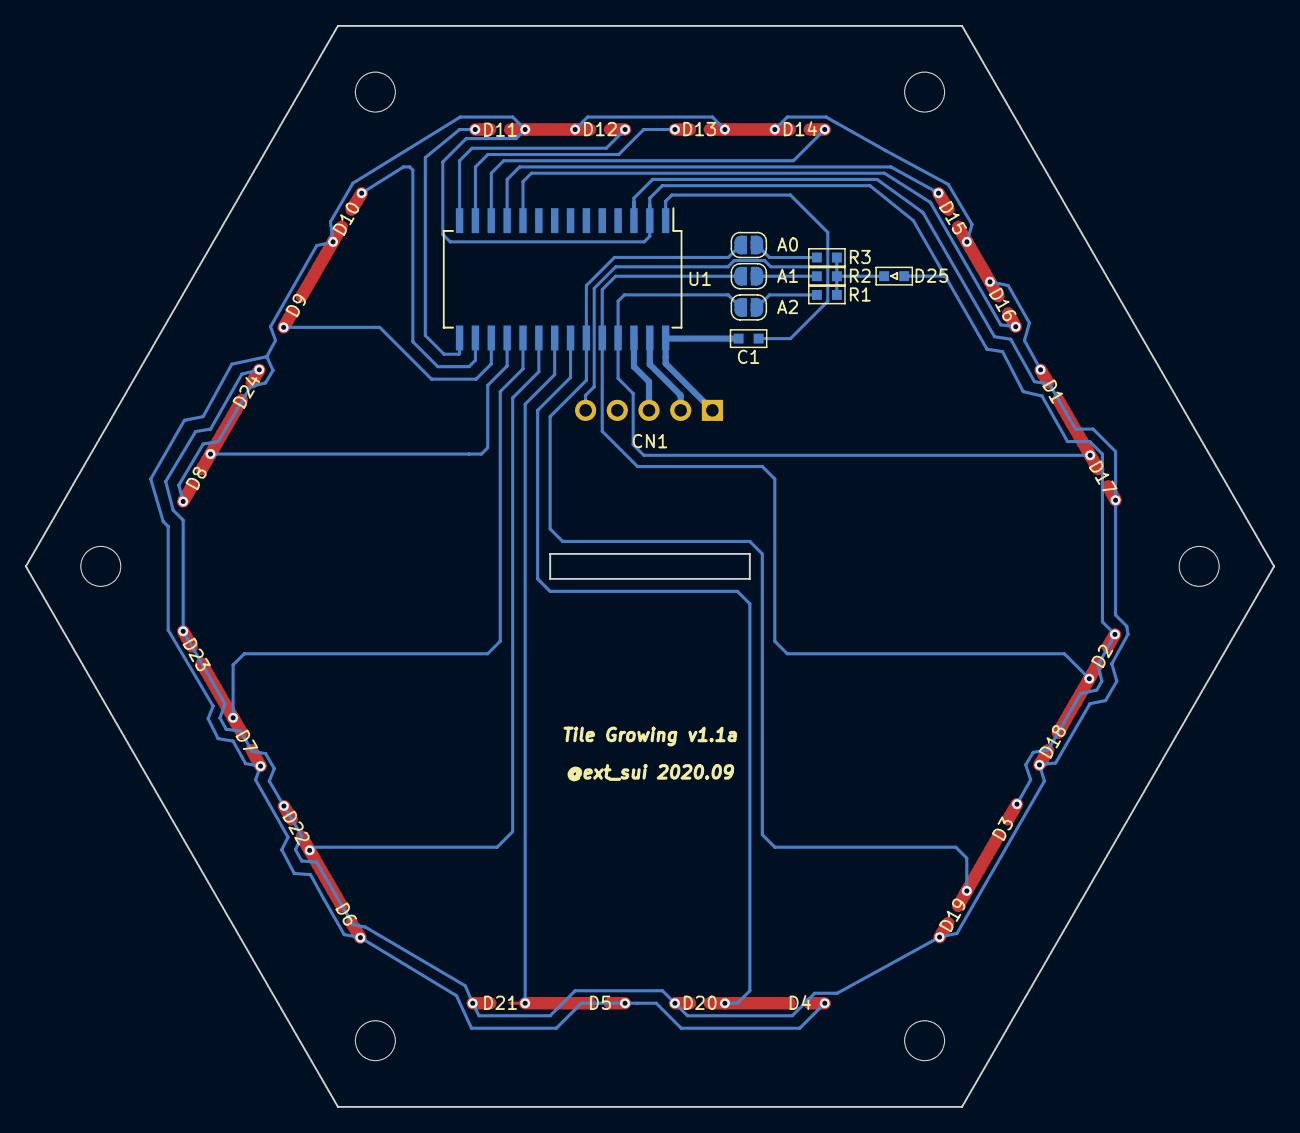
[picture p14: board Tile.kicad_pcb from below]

Board: 2 copper layers, 100.0 x 86.6 mm, 40 parts (9 on the bottom side), 26 nets.

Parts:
A0: A0; SolderJumper-2_P1.3mm_Open_RoundedPad1.0x1.5mm
A1: A1; SolderJumper-2_P1.3mm_Open_RoundedPad1.0x1.5mm
A2: A2; SolderJumper-2_P1.3mm_Open_RoundedPad1.0x1.5mm
C1: 0.1u; C_1608_HandSolderingCustom
CN1: Conn_01x05_Male; PinHeader_1x05_P2.54mm_Vertical
D1, D2, D3, D4, D5, D6, D7, D8, D9, D10, D11, D12, D13, D14, D15, D16, D17, D18, D19, D20, D21, D22, D23, D24: LED; LED_1608_HandSolderingCustom
D25: D; LED_1608_HandSolderingCustom
H1, H2, H3, H4, H5, H6: MountingHole; MountingHole_3.2mm_M3
R1, R2, R3: 39k; R_1608_HandSolderingCustom
U1: HT16K33-28SOP; SOIC-28W_7.5x18.7mm_P1.27mm

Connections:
+5V: C1.1, CN1.1, U1.28
GND: C1.2, CN1.5, U1.1
unnamed: D1.1, D2.1, D3.1, D4.1, D5.1, D6.1, D7.1, D8.1, D9.1, D10.1, D11.1, D12.1, D13.1, D14.1, D15.1, D16.1, D25.2, U1.2
unnamed: A2.2, D1.2, D17.2, U1.25
unnamed: D9.2, U1.17
unnamed: D10.2, U1.16
unnamed: D11.2, U1.15
unnamed: D12.2, U1.14
unnamed: D13.2, U1.13
unnamed: D14.2, U1.12
unnamed: D15.2, U1.11
unnamed: D16.2, U1.10
unnamed: D17.1, D18.1, D19.1, D20.1, D21.1, D22.1, D23.1, D24.1, U1.3
unnamed: A1.2, D2.2, D18.2, U1.24
unnamed: A0.2, D3.2, D19.2, U1.23
unnamed: D4.2, D20.2, U1.22
unnamed: D5.2, D21.2, U1.21
unnamed: D6.2, D22.2, U1.20
unnamed: D7.2, D23.2, U1.19
unnamed: D8.2, D24.2, U1.18
unnamed: D25.1, R1.2, R2.2, R3.2
unnamed: A2.1, R1.1
unnamed: A1.1, R2.1
unnamed: A0.1, R3.1
SCL: CN1.3, U1.26
SDA: CN1.2, U1.27

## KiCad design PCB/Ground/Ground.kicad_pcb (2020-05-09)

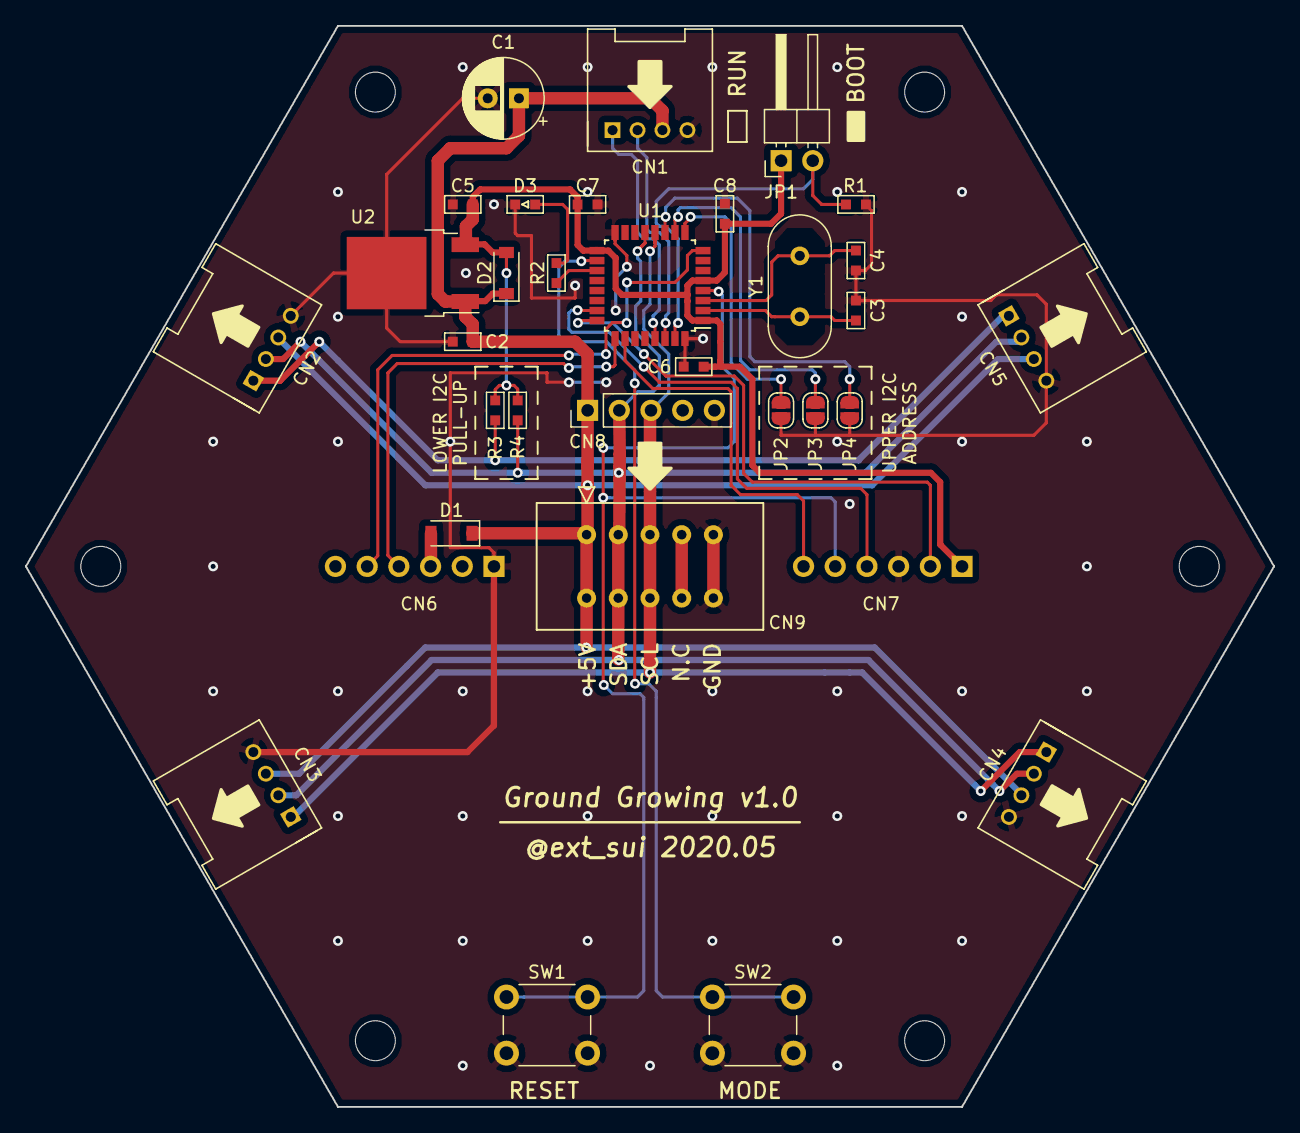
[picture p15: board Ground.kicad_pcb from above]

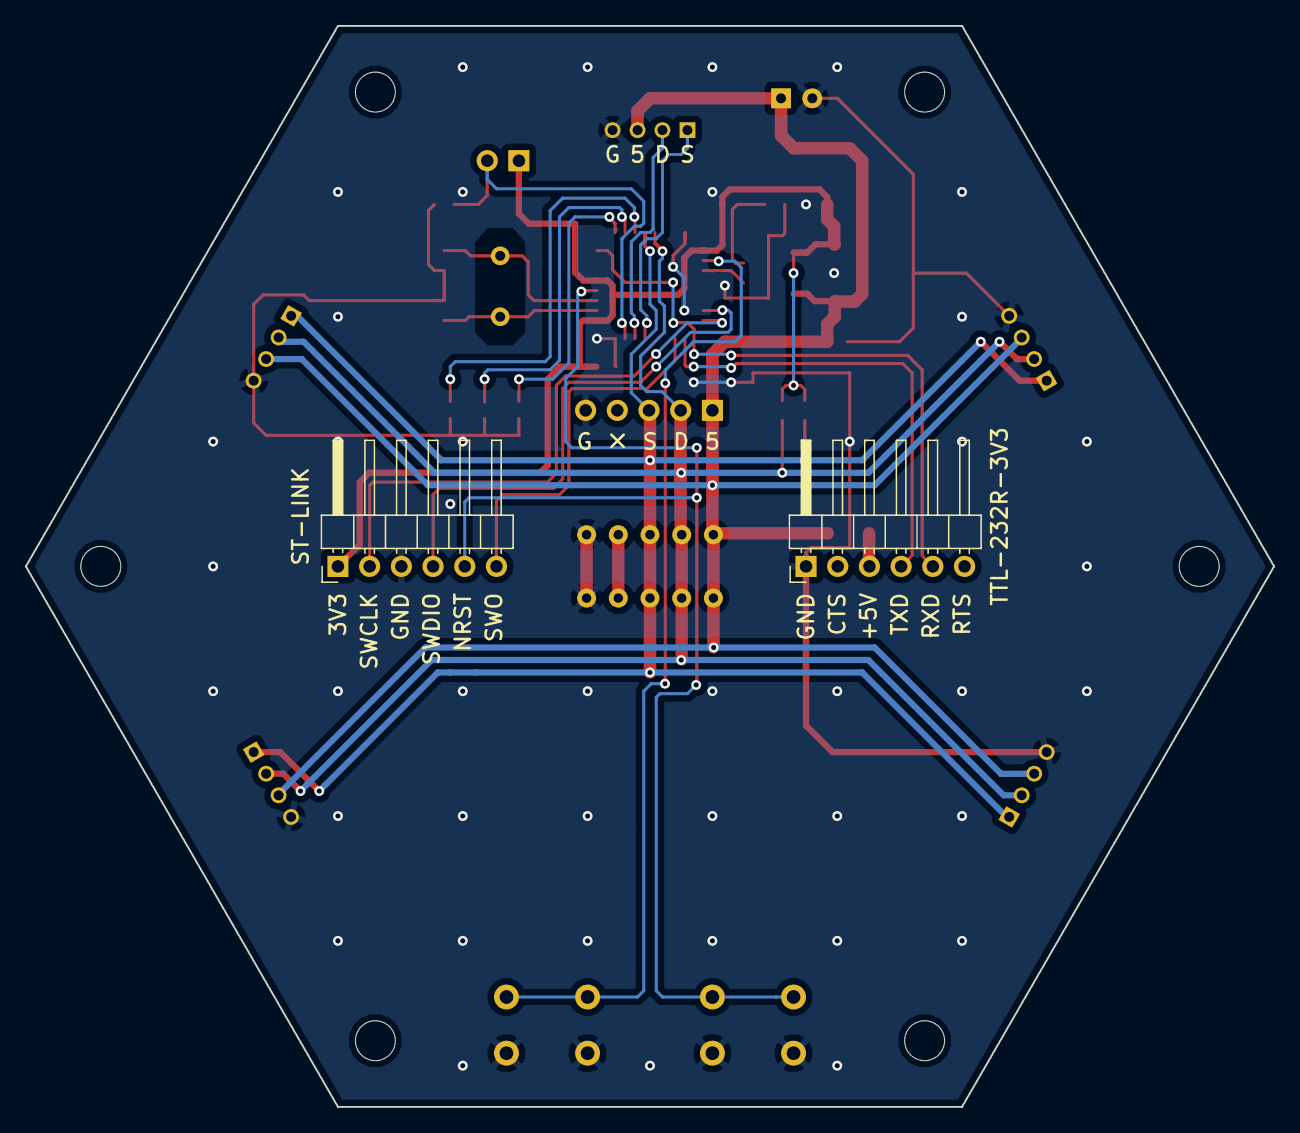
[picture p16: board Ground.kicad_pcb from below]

Board: 2 copper layers, 100.0 x 86.6 mm, 39 parts (2 on the bottom side), 23 nets.

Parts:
C1: 47uF; CP_Radial_D6.3mm_P2.50mm
C2: 0.1uF; C_1608_HandSolderingCustom
C3, C4: 22pF; C_1608_HandSolderingCustom
C5: 10uF; C_1608_HandSolderingCustom
C6, C7, C8: 0.1u; C_1608_HandSolderingCustom
CN1, CN2, CN3, CN4, CN5: GROVE; HW4-2.0-90D
CN6: TTL-232R-3V3; PinHeader_1x06_P2.54mm_Horizontal
CN7: ST-LINK; PinHeader_1x06_P2.54mm_Horizontal
CN8: Conn_01x05_Female; PinHeader_1x05_P2.54mm_Vertical
CN9: CardEdgeConnector5P; CONN_CARD_EDGE_395-010-521-201
D1, D2: SS2040FL; D_SOD-123
D3: LED; LED_1608_HandSolderingCustom
H1, H2, H3, H4, H5, H6: MountingHole; MountingHole_3.2mm_M3
JP1: JP_BOOT; PinHeader_1x02_P2.54mm_Horizontal
JP2, JP3, JP4: Jumper_NO_Small; SolderJumper-2_P1.3mm_Open_RoundedPad1.0x1.5mm
R1, R2, R3, R4: 10k; C_1608_HandSolderingCustom
SW1: RESET; SW_PUSH_6mm_H8mm
SW2: MODE; SW_PUSH_6mm_H8mm
U1: STM32F303K8T6; LQFP-32_7x7mm_P0.8mm
U2: NJM2845DL1-33; TO-252-2
Y1: 8MHz; Crystal_HC49-4H_Vertical

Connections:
3V3: C5.1, C6.2, C7.2, C8.2, CN7.1, D2.2, JP1.1, R3.1, R4.1, U1.1, U1.5, U1.17, U2.3
5V: C1.1, C2.1, CN1.3, CN2.3, CN3.3, CN4.3, CN5.3, CN8.1, CN9.1, D1.1, D2.1, U2.1
GND: C1.2, C2.2, C3.2, C4.2, C5.2, C6.1, C7.1, C8.1, CN1.4, CN2.4, CN3.4, CN4.4, CN5.4, CN6.1, CN7.3, CN8.5, CN9.5, D3.1, JP2.1, JP3.1, JP4.1, R1.2, SW1.1, SW2.2, U1.16, U1.32, U2.2
LOWER_SCL: CN2.1, CN3.1, CN4.1, CN5.1, CN8.3, CN9.3, R3.2, U1.12
LOWER_SDA: CN2.2, CN3.2, CN4.2, CN5.2, CN8.2, CN9.2, R4.2, U1.13
NRST: CN7.5, SW1.2, U1.4
unnamed: C3.1, U1.2, Y1.1
unnamed: C4.1, U1.3, Y1.2
unnamed: CN6.3, D1.2
unnamed: D3.2, R2.2
unnamed: JP1.2, R1.1, U1.31
unnamed: JP2.2, U1.9
unnamed: JP3.2, U1.10
unnamed: JP4.2, U1.11
unnamed: R2.1, U1.19
unnamed: SW2.1, U1.18
RXD: CN6.5, U1.8
SWCLK: CN7.2, U1.24
SWDIO: CN7.4, U1.23
SWO: CN7.6, U1.26
TXD: CN6.4, U1.25
UPPER_SCL: CN1.1, U1.29
UPPER_SDA: CN1.2, U1.30

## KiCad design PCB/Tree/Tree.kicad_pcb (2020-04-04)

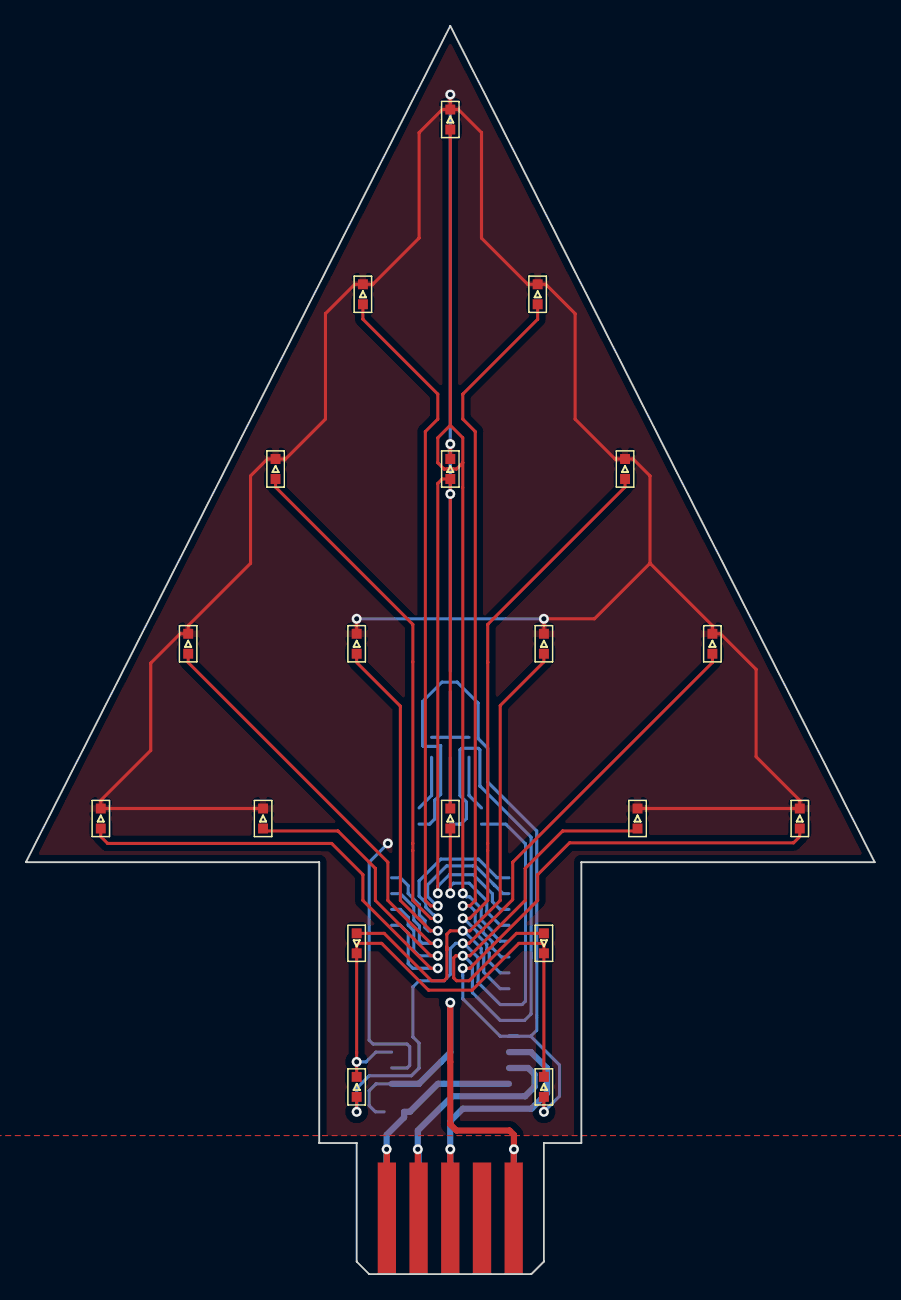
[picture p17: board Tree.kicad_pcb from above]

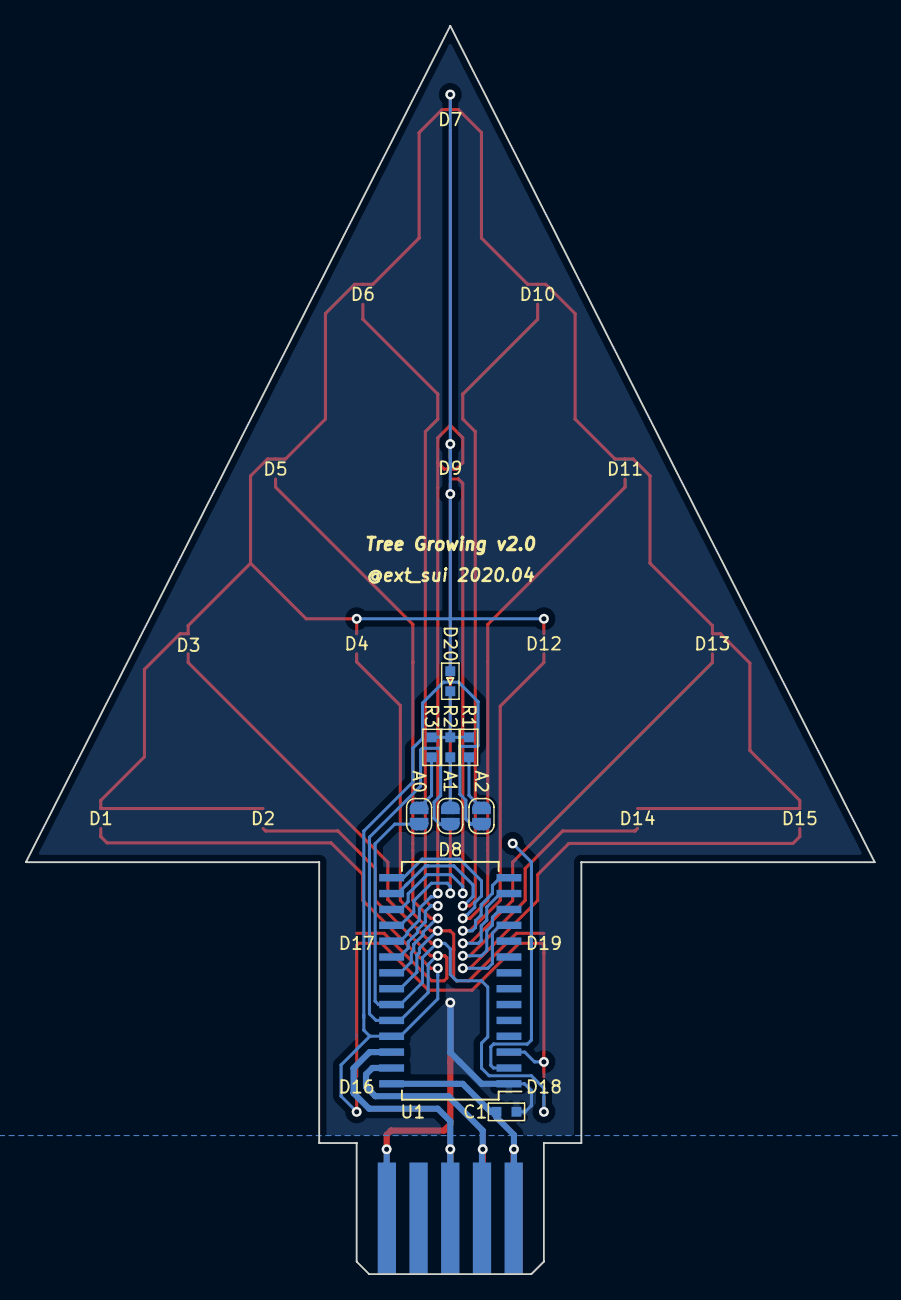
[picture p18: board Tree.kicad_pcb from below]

Board: 2 copper layers, 68.0 x 100.0 mm, 29 parts (9 on the bottom side), 25 nets.

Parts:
C1: 0.1u; C_1608_HandSolderingCustom
D1, D2, D3, D4, D5, D6, D7, D8, D9, D10, D11, D12, D13, D14, D15, D16, D17, D18, D19: LED; LED_1608_HandSolderingCustom
D20: D; LED_1608_HandSolderingCustom
J1: Conn_01x05; EDAC_5P_P2.54mm
JP1: A2; SolderJumper-2_P1.3mm_Open_RoundedPad1.0x1.5mm
JP2: A1; SolderJumper-2_P1.3mm_Open_RoundedPad1.0x1.5mm
JP3: A0; SolderJumper-2_P1.3mm_Open_RoundedPad1.0x1.5mm
R1, R2, R3: 39k; R_1608_HandSolderingCustom
U1: HT16K33-28SOP; SOIC-28W_7.5x18.7mm_P1.27mm

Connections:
+5V: C1.1, J1.1, U1.28
GND: C1.2, J1.5, U1.1
unnamed: D1.1, D2.1, D3.1, D4.1, D5.1, D6.1, D7.1, D8.1, D9.1, D10.1, D11.1, D12.1, D13.1, D14.1, D15.1, D20.2, U1.2
unnamed: D1.2, D16.2, JP1.2, U1.25
unnamed: D5.2, U1.21
unnamed: D6.2, U1.20
unnamed: D7.2, U1.19
unnamed: D8.2, U1.18
unnamed: D9.2, U1.17
unnamed: D10.2, U1.16
unnamed: D11.2, U1.15
unnamed: D12.2, U1.14
unnamed: D13.2, U1.13
unnamed: D14.2, U1.12
unnamed: D15.2, U1.11
unnamed: D16.1, D17.1, D18.1, D19.1, U1.3
unnamed: D2.2, D17.2, JP2.2, U1.24
unnamed: D3.2, D18.2, JP3.2, U1.23
unnamed: D4.2, D19.2, U1.22
unnamed: D20.1, R1.2, R2.2, R3.2
unnamed: JP1.1, R1.1
unnamed: JP2.1, R2.1
unnamed: JP3.1, R3.1
SCL: J1.3, U1.26
SDA: J1.2, U1.27

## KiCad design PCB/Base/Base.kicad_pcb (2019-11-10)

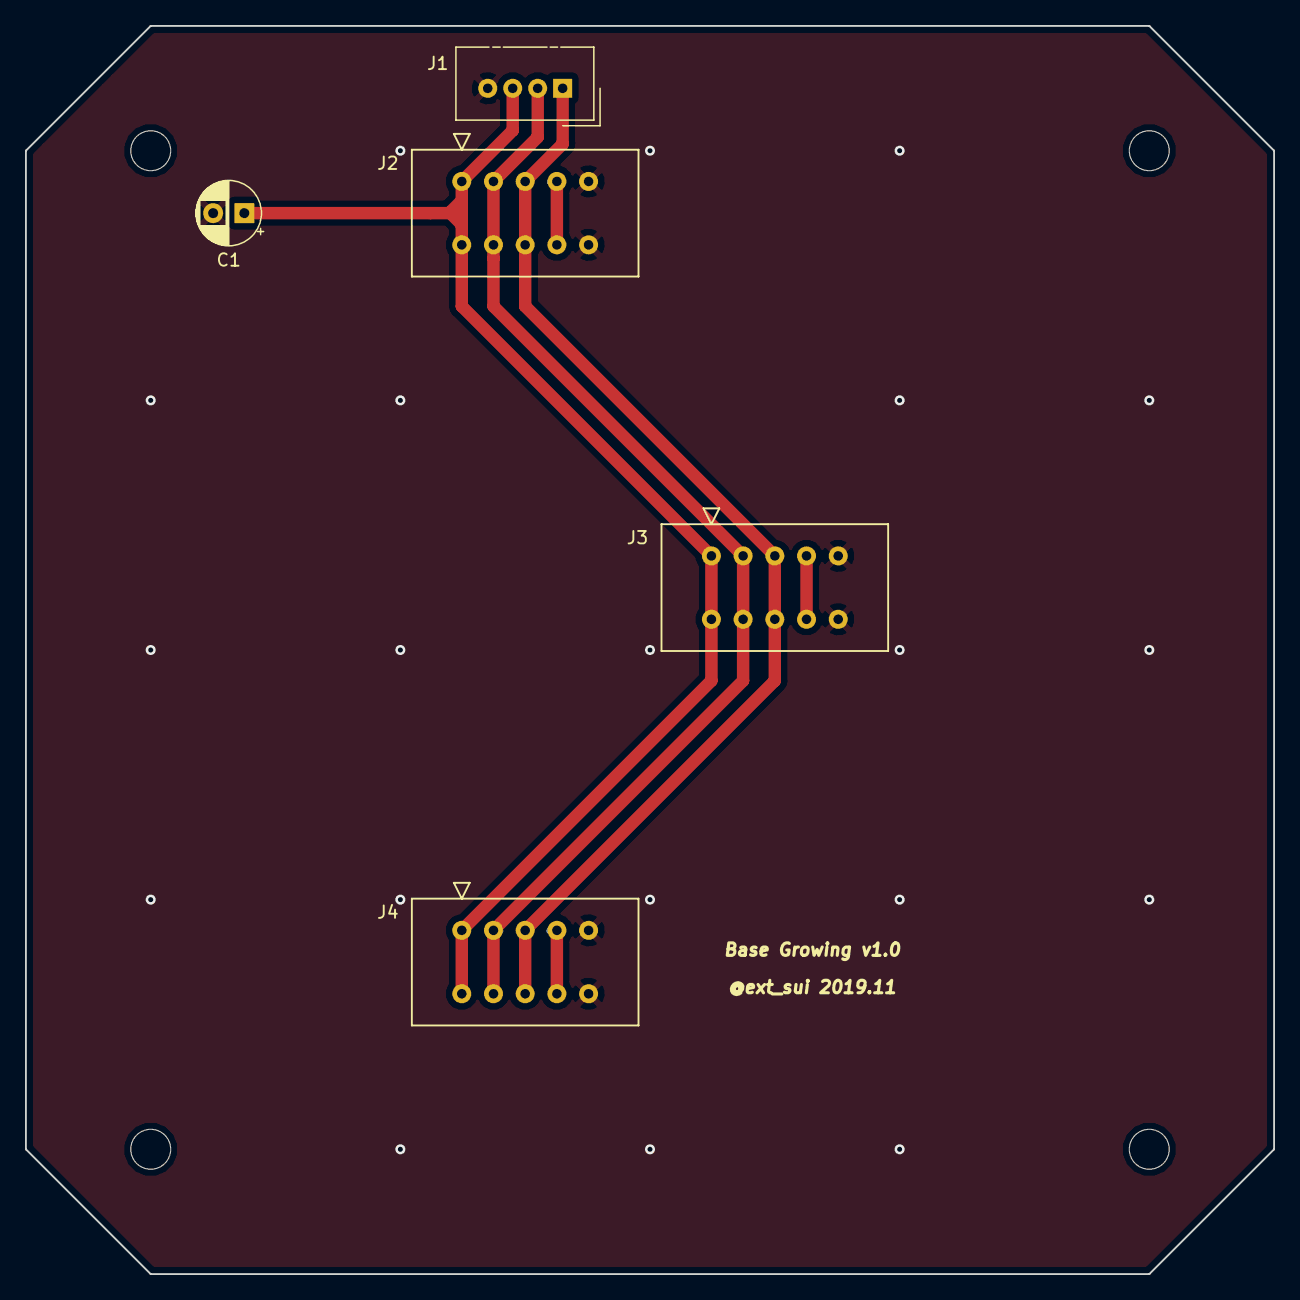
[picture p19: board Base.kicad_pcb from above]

Board: 2 copper layers, 100.0 x 100.0 mm, 9 parts (0 on the bottom side), 4 nets.

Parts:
C1: 10u; CP_Radial_D5.0mm_P2.50mm
J1: Conn_01x04; NS-Tech_Grove_1x04_P2mm_Vertical
J2, J3, J4: Conn_01x05; CONN_CARD_EDGE_395-010-521-201
REF1, REF2, REF3, REF4: MountingHole_3.2mm_M3

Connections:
+5V: C1.1, J1.3, J2.1, J3.1, J4.1
GND: C1.2, J1.4, J2.5, J3.5, J4.5
SCL: J1.1, J2.3, J3.3, J4.3
SDA: J1.2, J2.2, J3.2, J4.2

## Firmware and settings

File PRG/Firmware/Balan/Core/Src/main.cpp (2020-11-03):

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

/* Includes ------------------------------------------------------------------*/
#include "main.h"

/* USER CODE BEGIN Includes */
#include <stdio.h>
#include <string.h>
#include "Libraries/Balan.hpp"
#include "Libraries/Console.hpp"
/* USER CODE END Includes */

I2C_HandleTypeDef hi2c1;

UART_HandleTypeDef huart2;
DMA_HandleTypeDef hdma_usart2_rx;

void SystemClock_Config(void);
static void MX_GPIO_Init(void);
static void MX_DMA_Init(void);
static void MX_I2C1_Init(void);
static void MX_USART2_UART_Init(void);
/* USER CODE BEGIN 0 */
extern "C" int _write(int file, char *ptr, int len)
{
	for(int i = 0; i < len; i++)
	{
		ITM_SendChar(*ptr++);
	}
	return len;
}

/**
 * 現在のヒープの先頭を取得する
 *
 * @attension
 * 次に確保したときのアドレスを返すので、
 * 厳密にはヒープの先頭ではないことに注意。
 */
uint32_t QueryCurrentHeapTop()
{
	int *p = new int(0);
	delete p;
	return reinterpret_cast<uint32_t>(p);
}

/**
 * ヒープの末尾 (アドレス下位側) から指定サイズ分だけデバッグ用の値で埋める
 */
extern "C" void FillHeapForDebug(uint32_t bottom, uint32_t size, uint8_t fill)
{
	/*
	 *  +-----+ <-- 0x0000000
	 *  |     |
	 * ~~~~~~~~~
	 * ~~~~~~~~~
	 *  |     |
	 *  +-----+ <-- """about""" 0x20000388 (heap bottom)
	 *  |#####| <-- used
	 *  |  H  |
	 *  |  E  |
	 *  + - - + <-- margin
	 *  |//A//|
	 *  |//P//| <-- (fill)
	 *  |/////|
	 *  +-----+ <-- heap top (= bottom + size)
	 *  |     |
	 */
	uint32_t top = bottom + size;
	uint32_t margin = size / 2;
	memset(reinterpret_cast<void*>(top - margin), fill, margin);

	DEBUG_LOG("heap  : 0x%08lx-0x%08lx (%4lu) [fill=0x%02X, margin=%lu]\n",
		bottom, top, size, fill, margin);
}

/**
 * スタックの末尾 (アドレス上位側) から指定サイズ分だけデバッグ用の値で埋める
 */
extern "C" void FillStackForDebug(uint32_t bottom, uint32_t size, uint8_t fill)
{
	/*
	 *  +-----+ <-- 0x0000000
	 *  |     |
	 * ~~~~~~~~~
	 * ~~~~~~~~~
	 *  |     |
	 *  +-----+ <-- stack top (= bottom - size)
	 *  |/////|
	 *  |//S//| <-- (fill)
	 *  |//T//|
	 *  + -A- + <-- margin
	 *  |  C  |
	 *  |  K  |
	 *  |#####| <-- used ($sp)
	 *  +-----+ <-- 0x20003000 (stack bottom)
	 *  |     |
	 */
	uint32_t top = bottom - size;
	uint32_t margin = size / 2;
	memset(reinterpret_cast<void*>(top - margin), fill, margin);

	DEBUG_LOG("stack : 0x%08lx-0x%08lx (%4lu) [fill=0x%02X, margin=%lu]\n",
		top, bottom, size, fill, margin);
}

extern "C" void ConfigMemory()
{

	// *.map の設定シンボル
	extern char Min_Heap_Size asm("_Min_Heap_Size");
	extern char Min_Stack_Size asm("_Min_Stack_Size");
	// *.map のメモリ関連シンボル
	extern char stext asm("g_pfnVectors");	// text 開始アドレス (割り込みベクタテーブル)
	extern char sidata asm("_sidata");
	extern char etext asm("_etext");		// text 終了アドレス
	extern char sdata asm("_sdata");		// data 開始アドレス
	extern char edata asm("_edata");		// data 終了アドレス
	extern char sbss asm("_sbss");			// bss 開始アドレス
	extern char ebss asm("_ebss");			// bss 終了アドレス
	extern char end asm("end");			// data, bss の末尾 (heap 先頭)
	extern char estack asm("_estack");		// user_heap_stack の末尾 (stack 末尾)

	DEBUG_LOG("== Memory Configuration ==\n");
	DEBUG_LOG("-- Settings\n");
	DEBUG_LOG("Min_Heap_Size  : %p\n", &Min_Heap_Size);
	DEBUG_LOG("Min_Stack_Size : %p\n", &Min_Stack_Size);
	DEBUG_LOG("-- Symbols\n");
	DEBUG_LOG("stext  : %p\n", &stext);
	DEBUG_LOG("sidata : %p\n", &sidata);
	DEBUG_LOG("etext  : %p\n", &etext);
	DEBUG_LOG("sdata  : %p\n", &sdata);
	DEBUG_LOG("edata  : %p\n", &edata);
	DEBUG_LOG("sbss   : %p\n", &sbss);
	DEBUG_LOG("ebss   : %p\n", &ebss);
	DEBUG_LOG("end    : %p\n", &end);
	DEBUG_LOG("estack : %p\n", &estack);
	DEBUG_LOG("-- Areas\n");
	FillHeapForDebug(reinterpret_cast<uint32_t>(&end), reinterpret_cast<uint32_t>(&Min_Heap_Size), 0xEE);
	FillStackForDebug(reinterpret_cast<uint32_t>(&estack), reinterpret_cast<uint32_t>(&Min_Stack_Size), 0xCC);
	DEBUG_LOG("\n");
}

/* USER CODE END 0 */

/**
  * @brief  The application entry point.
  * @retval int
  */
int main(void)
{
  /* MCU Configuration--------------------------------------------------------*/

  /* Reset of all peripherals, Initializes the Flash interface and the Systick. */
  HAL_Init();

  /* Configure the system clock */
  SystemClock_Config();

  /* Initialize all configured peripherals */
  MX_GPIO_Init();
  MX_DMA_Init();
  MX_I2C1_Init();
  MX_USART2_UART_Init();
  /* Infinite loop */
  /* USER CODE BEGIN WHILE */
  ConfigMemory();
  DEBUG_LOG("Hello World!\n");
  Console *console = new Console(&huart2);
  console->Run();
  while (1)
  {
    /* USER CODE END WHILE */

    /* USER CODE BEGIN 3 */
  }
  /* USER CODE END 3 */
}

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


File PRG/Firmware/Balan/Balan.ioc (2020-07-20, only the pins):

Mcu.UserName=STM32F303K8Tx
PA13.Signal=SYS_JTMS-SWDIO
PA14.Signal=SYS_JTCK-SWCLK
PA15.Signal=USART2_RX
PA2.Signal=USART2_TX
PA3.GPIO_Label=I2C_SLAVE_ADDR_A0
PA3.Signal=GPIO_Input
PA4.GPIO_Label=I2C_SLAVE_ADDR_A1
PA4.Signal=GPIO_Input
PA5.GPIO_Label=I2C_SLAVE_ADDR_A2
PA5.Signal=GPIO_Input
PA6.GPIO_Label=I2C_LOWER_SCL
PA6.Signal=GPIO_Output
PA7.GPIO_Label=I2C_LOWER_SDA
PA7.Signal=GPIO_Output
PA9.GPIO_Label=DEBUG_LED
PA9.Signal=GPIO_Output
PB3.Signal=SYS_JTDO-TRACESWO
PB6.Signal=I2C1_SCL
PB7.Signal=I2C1_SDA

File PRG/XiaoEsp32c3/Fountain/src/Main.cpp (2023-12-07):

#include <Arduino.h>
#include <stdint.h>
#include "Ht16k33.h"
#include "MetaSegmentTable.h"

#include "Button.h"
#include "Building.h"
#include "Volume.h"
#include "Shell.h"
#include "Util.h"

namespace {
    
////////////////////////////////////////////////////////////////////////////////
//  ピン関連
////////////////////////////////////////////////////////////////////////////////
constexpr int PinNumberLeftButton = D8;
constexpr int PinNumberRightButton = D9;
Button g_LeftButton;
Button g_RightButton;

////////////////////////////////////////////////////////////////////////////////
//  ボリューム関連
////////////////////////////////////////////////////////////////////////////////
constexpr int PinNumberLeftVolume = A0;
constexpr int PinNumberRightVolume = A1;
Volume g_LeftVolume;
Volume g_RightVolume;

// RC フィルタ比率 (1~99)
constexpr int LowPassFilterRate = 80;
RcFilter g_LeftVolumeFilter(LowPassFilterRate);
RcFilter g_RightVolumeFilter(LowPassFilterRate);

constexpr uint32_t LeftVolumeLevel = 16; // 輝度調整向け
constexpr uint32_t RightVolumeLevel = 100;  // 範囲は適当

TwoWire& g_Wire = Wire;

}

constexpr uint8_t NumberSegmentTable[] =
{
    0xFC,   // 0
    0x60,   // 1
    0xDA,   // 2
    0xF2,   // 3
    0x66,   // 4
    0xB6,   // 5
    0xBE,   // 6
    0xE4,   // 7
    0xFE,   // 8
    0xF6,   // 9
    0xEE,   // A
    0x3E,   // b
    0x1A,   // c
    0x7A,   // d
    0x9E,   // E
    0x8E,   // F
};

Building g_Building;

void setup()
{
    g_Wire.begin(D10, D7, 400000);

    g_Building.Initialize(&g_Wire);
    g_Building.Clear();
    g_Building.Update();

    // USB ポートが開くまで一定時間待機
    // USB-CDC 非搭載のものは常に true
    Serial.begin(115200);
    constexpr uint32_t UsbSerialTimeoutMilliSeconds = 500;
    uint32_t start = millis();
    while (!Serial) {
        // TODO: 判定式が正しいか要確認
        if (start + UsbSerialTimeoutMilliSeconds < millis()) {
            break;
        }
    }
    LOG("Build: %s %s\n", __DATE__, __TIME__);
    LOG("Serial: Initialized.\n");

    g_LeftButton.Initialize(PinNumberLeftButton, false, false); // プルアップ抵抗が外付け
    g_RightButton.Initialize(PinNumberRightButton, false, true);
    LOG("Button: Initialized.\n");

    g_LeftVolume.Initialize(PinNumberLeftVolume, &g_LeftVolumeFilter, LeftVolumeLevel);
    g_RightVolume.Initialize(PinNumberRightVolume, &g_RightVolumeFilter, RightVolumeLevel);
    LOG("Volume: Initialized.\n");

    LOG("Building Startup!\n");
}

void loop()
{
    int currentTick = millis();

    // シリアル経由コマンド実行
    if (Serial.available()) {
        uint8_t data = Serial.read();
        ParseAndExecuteCommand(data);
    }

    g_LeftButton.Update();
    g_RightButton.Update();
    g_LeftVolume.Update();
    g_RightVolume.Update();

    static int s_NextUpdateTick = 1000; // TORIAEZU:
    if (currentTick + 500 < s_NextUpdateTick)
    {
        return;
    }
    s_NextUpdateTick += 500;

    // TODO: 輝度更新と数字更新の頻度は独立させるべき

    // 輝度更新はあまり高頻度では行わない
    uint32_t brightness = g_LeftVolume.GetLevel();
    g_Building.SetBrightness(brightness);

    static bool s_ReverseMode = false;
    if (g_LeftButton.WasSingleClicked()) {
        s_ReverseMode = !s_ReverseMode;
        LOG("Mode Changed! (--> Reverse=%d)\n", s_ReverseMode);
        g_LeftButton.ClearEvents();
    }
/*
    // 順繰りに7セグ7セグの表示を自動更新し続ける
    static int s_Number = 0;
    s_Number++;
    if (s_Number >= 10) {
        s_Number = 0;
    }

    if (s_ReverseMode)
    {
        g_Building.Fill();
    }
    else
    {
        g_Building.Clear();
    }
    uint8_t numberPattern = NumberSegmentTable[s_Number];
    for (int metaSeg = 0; metaSeg < 8; metaSeg++)
    {
        if (numberPattern & (1 << (7 - metaSeg))) {
            for (int y = 0; y < Building::DigitY; y++)
            {
                for (int x = 0; x < Building::DigitX; x++)
                {
                    uint8_t pattern = MetaSegmentTable[metaSeg][y][x];

                    if (s_ReverseMode)
                    {
                        g_Building.AndPattern(x, y, pattern);
                    }
                    else
                    {
                        g_Building.OrPattern(x, y, pattern);
                    }
                }
            }
        }
    }
    g_Building.Update();
*/
}

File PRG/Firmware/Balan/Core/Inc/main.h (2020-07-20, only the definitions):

#define I2C_SLAVE_ADDR_A0_Pin GPIO_PIN_3
#define I2C_SLAVE_ADDR_A0_GPIO_Port GPIOA
#define I2C_SLAVE_ADDR_A1_Pin GPIO_PIN_4
#define I2C_SLAVE_ADDR_A1_GPIO_Port GPIOA
#define I2C_SLAVE_ADDR_A2_Pin GPIO_PIN_5
#define I2C_SLAVE_ADDR_A2_GPIO_Port GPIOA
#define I2C_LOWER_SCL_Pin GPIO_PIN_6
#define I2C_LOWER_SCL_GPIO_Port GPIOA
#define I2C_LOWER_SDA_Pin GPIO_PIN_7
#define I2C_LOWER_SDA_GPIO_Port GPIOA
#define DEBUG_LED_Pin GPIO_PIN_9
#define DEBUG_LED_GPIO_Port GPIOA

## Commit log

2019-11-07 [add] Grass,Tree,Land初期登録
    [Grass-B.Cu.gbl, Grass-B.Mask.gbs, Grass-B.SilkS.gbo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]
2019-11-07 [update] Grass v2.0登録
    Grass v1.0->v2.0
    コネクタ形状をカードエッジコネクタに対応
    [Grass-B.Cu.gbl, Grass-B.Mask.gbs, Grass-B.SilkS.gbo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]
2019-11-10 [add] Base v1.0新規作成
    libraryにカードエッジコネクタ(5-pin)を追加
    [Base-B.Cu.gbl, Base-B.Mask.gbs, Base-B.Paste.gbp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]
2019-11-14 [update] Grass v2.1登録
    Grass v2.0->v2.1
    * カードエッジコネクタのPCBのパッドを'SMD'から'コネクタ'に修正
    (デフォルトライブラリのカードエッジコネクタ系を参考)
    * コネクタ部の角を45度に修正
    * コネクタ部のF.MaskとB.Maskの範囲を付け根までに修正
    [Grass-B.Cu.gbl, Grass-B.Mask.gbs, Grass-B.Paste.gbp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]
2019-12-30 [add] HouseのPCBを作成
    [House.kicad_pcb, House.sch]
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2020-01-13 [update] HouseのLED仮位置決め完了
    [House.kicad_pcb]
2020-01-13 [update] HouseのLEDシルク裏返しと仮配線
    [House.kicad_pcb]
2020-01-13 [update] Houseの配線完了(初版)
    [House.kicad_pcb]
2020-01-13 [update] Houseの配線改善(表面横方向配線削減)
    表面横方向配線を削減した結果、
    下中部に横方向の跨ぎ配線が発生。
    [House.kicad_pcb]
2020-01-14 [update] Houseの配線改善(表面最小化)
    下中部の横方向の跨ぎ配線を極力裏面に移動。
    TODO:
    * I2Cアドレスパッドの表面配線を一つ横の窓に合わせる
    [House.kicad_pcb]
2020-01-15 [update] Houseの配線改善(部品位置調整)
    IC位置を窓と下部の中央に移動。
    I2Cアドレスパッドとバージョンシルクも合わせて移動。
    [House.kicad_pcb]
2020-01-15 [update] Houseの配線改善(表面配線位置調整)
    表面配線が可能な限り線対象になるように位置を調整。
    * ICの横4本配線の位置の中心化
    * GNDビアの位置の調整
    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
    [House.kicad_pcb]
2020-01-16 [update] Houseの配線改善(ICの横4本配線の位置の中心化)
    [House.kicad_pcb]
2020-01-18 [update] Houseの配線改善(目、ビア位置、屋根裏調整)
    * 窓際の表面縦配線の位置を1個内側に移動して目に見えるように修正。
    * 各種ビア位置をほぼ線対称になるように移動。
    * 屋根裏の裏面配線を外形線に沿うように大きくした。
    [House.kicad_pcb]
2020-02-28 [update] House v1.0登録
    * 「シルクからパッドを除外」にチェックを追加(seeed準拠)
    * 製造年月を2020.02から2020.03に修正
    [House-B.Cu.gbl, House-B.Mask.gbs, House-B.Paste.gbp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]
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2020-04-01 [update] Tree回路図のコネクタとLED位置を修正 #2
    * コネクタをカードエッジ(5P)に変更
    * 回路図上のLED配置を他の機器に合わせて変更
    (元々基板上の配置とずれていた)
    [Tree.sch]
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2020-04-04 [update] Treeの左右で幅が異なっていたのを修正 #2
    * 中心から右が34mm、左が33.5mmだったのを34mmに統一
    [Tree-B.Cu.gbl, Tree-B.Mask.gbs, Tree-B.Paste.gbp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]
2020-04-04 [update] Tree v2.0登録 #2
    * Tree v1.0 --> v2.0
    * 作成日付も合わせて更新
    [Tree-B.Cu.gbl, Tree-B.Mask.gbs, Tree-B.Paste.gbp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]
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2020-04-16 [add] Groundベースを作成 #4
    * 形状が同じのためTileのe3d4f6bをベースとした。
    [Ground.kicad_pcb, Ground.sch]
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2020-04-18 [update] Tileの回路図のピンヘッダの種類を変更 #3
    * Tile側のピンヘッダがFemaleになっていたのをMaleに変更
    [Tile.kicad_pcb, Tile.sch]
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2020-04-18 [update] Groundの回路図の電源供給周りを修正 #4
    * 5V供給がUPPER_GROVEとTTL-232R-3V3からであることを明示
    * USB保護用にTTL-232R-3V3の5Vにショットキーバリアダイオードを追加
    * 三端子レギュレータ保護用にショットキーバリアダイオードを追加
    [Ground.sch]
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2020-04-22 [update] Groundの部品配置のベース作成 #4
    * 電解コンデンサC1のシルク幅を5.0mmから6.3mmのものに変更
    * GROVEコネクタの位置を厳密な線分の中心に移動
    * 小物・シルク等を調整
    [Ground.kicad_pcb, Ground.sch]
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2020-04-26 [update] Groundの回路図のI2C_JP周りを修正 #4
    * LOWER_I2Cのプルアップ抵抗のJPを削除
    (未使用の場合は抵抗を付けないだけで済むため)
    * UPPWER_I2CのスレーブアドレスのJPを追加
    [Ground.sch]
2020-04-26 [update] Groundの配線への回路図反映と電解コンデンサ位置修正
    * 電解コンデンサC1を左に移動することでCN5の+5Vラインを
    中央から配線できるように修正した。
    [Ground.kicad_pcb]
2020-04-28 [update] Groundの回路図のCN2-5のI2Cバス配線を改善 #4
    * CN2-5のI2Cバス配線を点対称になるように修正
    ※コネクタ位置が逆順になるため線対称にすることは不可能
    [Ground.kicad_pcb]
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2020-04-30 [update] GroundのD1,D2のフットプリントを変更 #4
    * 実物合わせの結果123Fより123の方が適合していた
    [Ground.kicad_pcb, Ground.sch]
2020-05-01 [update] Groundの配線改善(+5V配線, BOOT) #4
    * C5(レギュレータ直近)を反転
    * +5V配線幅を0.5mmから1.0mmに拡大
    * JP1(BOOT)にOPEN/SHORTそれぞれの機能をシルクで記載
    (RUN/BOOT)
    [Ground.kicad_pcb]
2020-05-03 [update] Groundの配線改善(3V3配線, シルク) #4
    * IC周辺の3V3配線を他の配線より優先するように修正
    * I2C関連のコネクタ部の裏側にシルクを追加
    * JP2-4の配線を表面から裏面に変更し配線長を短縮
    * ST-LINK関連の配線を下に移動しGNDベタ用ビアを追加
    * IC周辺のビア位置を整頓
    [Ground.kicad_pcb]
2020-05-03 [update] Groundの配線改善(SW, PULL-UP) #4
    * SW1,2の配線を表面から裏面に移動
    * LOWER I2C PULL-UP を JP2-4 に合わせるために基板左上に移動
    * カードエッジコネクタとの距離を離すためにD1の位置を移動
    [Ground.kicad_pcb]
2020-05-04 [update] Groundの配線改善(GNDビア) #4
    * GNDビアを10mm間隔で配置できる箇所に配置
    [Ground.kicad_pcb]
2020-05-04 [update] TileのIC位置を移動 #3
    * ICを手前の裏に配置すると表面に配線やビアが
    見えてしまうので奥側に移動
    [Tile.kicad_pcb]
2020-05-05 [update] Tileの配線改善(裏面外周) #3
    * 裏面外周の配線を60度に沿うように修正
    [Tile.kicad_pcb]
2020-05-05 [update] Ground v1.0新規作成 #4
    [Ground-B.Cu.gbl, Ground-B.Mask.gbs, Ground-B.Paste.gbp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]
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2020-05-06 [update] Tileの配線改善(GNDビア, 配線全体) #3
    * GNDビアを等間隔に空けるためにIC位置をさらにずらした
    * 基板下から中央への配線のY座標を左右で統一
    [Tile.kicad_pcb]
2020-05-06 [update] Tileのロゴマークを修正 #3
    * ロゴの外周円の位置を中央に修正
    * "Board" を逆位置だったのを正位置に修正
    * 家の屋根が歪んでいたのを修正
    [Tile.kicad_pcb]
2020-05-09 [update] Tileの配線改善(DRC, 名前, ロゴ) #3
    * DRCエラー(D17-Pad1)を修正
    * 5-PINヘッダの名前をJ1からCN1に修正
    * GardeningBoardのロゴの"Gardening"文字を右に移動
    [Tile.kicad_pcb, Tile.sch]
2020-05-09 [update] Tile v1.0新規作成 #3
    [Tile-B.Cu.gbl, Tile-B.Mask.gbs, Tile-B.Paste.gbp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]
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2020-07-15 (Balan) SoftwareI2C のピン制御をレジスタ直叩きに修正 #9
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2020-09-09 (Tile) スレーブアドレス選択のシルク誤りを修正 #17
    [Tile.kicad_pcb]
2020-09-09 (Tile) ダイオードのシルクを D26 から D25 に修正 #17
    [Tile-B.Cu.gbl, Tile-B.Mask.gbs, Tile-B.Paste.gbp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]
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2020-09-09 (Tile) v1.1 --> v1.1a #20
    [Tile-B.Cu.gbl, Tile-B.Mask.gbs, Tile-B.Paste.gbp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]
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2020-09-26 (Balan) I2C スレーブ同期受信の動作確認 #11
    [Balan.xlsx]
2020-09-28 (Balan) Pump -> Balan の通信プロトコルを検討 #11
    [Balan.xlsx]
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2020-10-21 (Balan) I2C スレーブの受信フレーム損失不具合の解消 #11
    * スレーブ割り込み関連ビットは PE=1 でも書き換え可能だった。
    * 割禁中に PE=0 にしていたのが原因だった。
    [Balan.xlsx]
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2020-11-02 (Balan) Register, Reset コマンドの追加 #31
    [Balan.xlsx]
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2020-12-12 (Sprinkler) UI の調整 #36
    * .NETFramework への変換で Button の文字がつぶれていたのを修正
    * TextBox の Window のリサイズ時の挙動が適当だったのを修正
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2020-12-15 (Sprinkler) NoteOn で点灯させ NoteOff で消灯させるように修正 #36
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2021-01-07 (Balan) CubeIDE Update により設定ファイルが追加されたので除外対象を修正
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2021-02-21 (Cad) 実体図形と 2D データを作成 #43
    [Floor.dxf]
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2021-04-07 (Balan) SetStepTiming コマンドの追加 #47
    [Balan.xlsx]
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2021-04-19 (Balan) StepTiming を 1byte から 2byte に変更 #47
    [Balan.xlsx]
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2021-04-26 (Pump) PumpScript にファイル読み込みを追加 #49
    [TestScript.gbs]
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2021-05-08 (Sprinkler) 音声同時再生を追加 #55
    * 10秒くらいから異常なパターン崩れが発生するので要修正
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2021-05-16 (Sprinkler) 指定タイミングの最初のコマンドが実行されていなかったのを修正 #55
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2021-08-30 (Pcb) Pillar の回路図のベースを作成 #60
    [Pillar.kicad_pcb, Pillar.sch]
2021-08-30 (Pcb) Pillar の回路図 v0 完成 #60
    [Pillar.sch]
2021-08-30 (Pcb) Pillar の既存パーツのネットリスト対応作成 #60
    [Pillar.sch]
2021-08-30 (Pcb) Pillar で使用する XIAO と DFP のフットプリントを作成 #60
    [Pillar.sch]
2021-08-30 (Pcb) ネットリストを修正してフットプリント配置エラーを解決 #60
    [Pillar.kicad_pcb, Pillar.sch]
2021-08-31 (Pcb) OLED のフットプリント追加と各種パーツの位置修正 #60
    [Pillar.kicad_pcb, Pillar.sch]
2021-09-05 (Pcb) Mode スイッチの割り当て変更と抵抗のディスクリート部品化 #60
    * Mode スイッチの割り当ては XIAO 拡張ボードの UserButton に合わせたため。
    * ディスクリート化は基板領域が余っているため。
    [Pillar.kicad_pcb, Pillar.sch]
2021-09-05 (Pcb) OLED, XIAO のフットプリントに情報を追加して位置を再調整 #60
    [Pillar.kicad_pcb, Pillar.sch]
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2021-09-07 (Pcb) 配線改善：3V3 ラインの直線化と外周 GND 打ち #60
    [Pillar.kicad_pcb]
2021-09-10 (Pcb) 配線改善：SPI の配線の間に GND ビア打ち #60
    [Pillar.kicad_pcb]
2021-09-10 (Pcb) 配線改善：XIAO 周辺の電源と I2C 配線を改善 #60
    [Pillar.kicad_pcb]
2021-09-10 (Pcb) 配線改善：ティアドロップ付与と全体の均一 GND ビア打ち #60
    [Pillar.kicad_pcb]
2021-09-12 (Pcb) Pillar v1.0 ガバーデータ作成 #60
    [Pillar-B.Cu.gbl, Pillar-B.Mask.gbs, Pillar-B.Paste.gbp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]
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2021-10-21 (Pillar) USB-CDC が検出できない場合でも再生可能状態に遷移するように修正 #63
    [BadApple.ino]
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2021-10-24 (Pillar) OLED にフォントを追加して初期化失敗時にエラーを表示できるように修正 #62
    [Pillar.ino]
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2021-11-03 (Pillar) ボタン更新処理をタイマ割り込みから呼び出すように修正 #66
    * BadApple 再生のように重い処理中だとメインループでのボタン更新処理が滞ってダブルクリック判定ができなかったため。
    * タイマ割り込みを使用することでボタンのイベント取得処理に割り込み排他を付与。
    [Pillar.ino]
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2021-11-03 (Pillar) Pump ライブラリを複製 (ビルド不可) #68
    * ファイル名変更関連の修正 (hpp --> h) 以外はしていない
    [PumpUtil.cpp]
2021-11-03 (Pillar) Pump ライブラリを最低限動作する状態に修正 #68
    [Test.gbs]
2021-11-03 (Pillar) 状態遷移時にボタンイベントを次の状態に引き継がないように修正 #68
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2022-04-06 (Pillar) 最適化オプションを -O0 から -Os に修正
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2023-04-28 (Sprinkler) Pillar 用スクリプト出力を追加 (登録)
    [reg.gbs]
2023-04-28 (Pillar) スクリプトモードを展示会デモ用に修正
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2023-08-29 (Building) Building 用のプロジェクトを作成 #75
    [Building.kicad_pcb, Building.sch]
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2023-09-06 (Building) 回路図内のラベルを3セット独立に修正 #75
    [Building.kicad_pcb, Building.sch]
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2023-09-09 (Building) OSL60362_XX のシルクが別レイヤになっていたのを修正 #75
    [Building.kicad_pcb]
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2023-09-14 (Building) 配線最適化2 (CA1-6 を上部に束ねるように修正) #75
    [Building.kicad_pcb]
2023-09-14 (Building) 配線最適化3 (配線幅を0.5mmに統一) #75
    [Building.kicad_pcb]
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2023-09-17 (Building) 基板外形を 7mm から 8mm に拡張 #75
    * HT16K33 の脇が狭すぎかつ I2C 信号を通せそうになかったため
    [Building.kicad_pcb]
2023-09-17 (Building) SCL/SDA/5V の仮配線 #75
    [Building.kicad_pcb]
2023-09-18 (Building) SCL/SDA の配線位置確定 #75
    [Building.kicad_pcb]
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2023-09-18 (Building) Building v1.0 ガーバーデータ作成 #75
    [Building-B.Cu.gbl, Building-B.Mask.gbs, Building-B.Paste.gbp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]
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2023-10-12 (Fountain) Pillar 基板をコピー #77
    [Fountain.kicad_pcb, Fountain.sch]
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2023-10-19 (Fountain) JTAG コネクタと電解コンを追加および VOL/SW 位置調整 #77
    [Fountain.kicad_pcb, Fountain.sch]
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2023-10-22 (Fountain) 配線調整とシルク修正 #77
    [Fountain.kicad_pcb]
2023-10-22 (Fountain) GND ビア打ちとティアドロップ追加 #77
    [Fountain.kicad_pcb]
2023-10-22 (Fountain) v1.0 ガーバーデータ作成 #77
    [Fountain-B.Cu.gbl, Fountain-B.Mask.gbs, Fountain-B.Paste.gbp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]
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2023-11-02 (BuildingPainter) 各セグメントを若干太めに修正
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2023-11-03 (BuildingPainter) 7セグのクリックでON/OFFを操作できるように修正
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2023-11-03 (BuildingPainter) 7セグ消灯時の色を白寄りを黒よりに修正
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2023-11-03 (Fountain) 左ボリュームで輝度更新ができるように修正
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

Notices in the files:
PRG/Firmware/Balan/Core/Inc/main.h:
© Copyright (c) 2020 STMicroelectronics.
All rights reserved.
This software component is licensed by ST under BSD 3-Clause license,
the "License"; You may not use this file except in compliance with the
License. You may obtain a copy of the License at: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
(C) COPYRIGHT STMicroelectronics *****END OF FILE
